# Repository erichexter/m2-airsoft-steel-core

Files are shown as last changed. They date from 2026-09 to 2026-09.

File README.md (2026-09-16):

# M2 Airsoft — Steel Core Conversion

> **Part names.** Every part has one name, used identically in Fusion, in `stl/`, and in
> these notes — `ST-` you weld, `HW-` you buy, `PR-` you print. See **[docs/PARTS.md](docs/PARTS.md)**
> for the full catalogue and the old-name mapping. Note that **L and R are the physical
> sides of the gun**, and the donor mesh names had them backwards.

A welded steel structural core for a 3D-printed Browning M2 airsoft replica.

The assembled replica

*Blue is steel you weld, brass is hardware you buy, grey is 3D printed.*

**▶ [Three-minute walkthrough video](https://github.com/erichexter/m2-airsoft-steel-core/releases/tag/v1.0)**
— cross-sections, what is steel, how it goes together.

Instead of printing the receiver as a structural part, this design puts all the load into a
single piece of **2" × 3" × 0.120" wall rectangular steel tube**. The printed parts become
non-structural cosmetic skins that bolt and glue over it, plus a printed cradle that carries the
airsoft engine and hop-up.

The result is stiffer, survives being carried by the barrel or dropped, and puts the hinge,
pintle and barrel mounts into welded steel rather than plastic.

**~11.2 lb of steel** (including the EMT barrel) and **~3.6 lb of PLA** — call it **~17 lb
finished** with the engine and hardware. The PLA figure assumes a 2mm shell and light infill;
printed solid the same parts would be 8.9 lb.
For scale: a real M2HB is 84 lb; commercial airsoft M2 replicas run 33–44 lb.

---

## What's here

```
docs/PARTS.md              Parts catalogue — every name, in one place. START HERE
docs/PRINTING.md           Orientation per part, settings, and why the long panels warp
docs/SLICER-AGENT-PROMPT.md  Self-contained brief to hand an agent on the slicer machine
docs/BUILD-NOTES.md        Full build notes: cut list, coordinates, weld plan, gotchas
docs/NATIVE-REBUILD.md     How the donor meshes were reauthored as native geometry

stl/PR-*.stl               The 18 printed parts, ready to slice
stl/print-aids/            PR-11/PR-12 with snap-off corner pads — print THESE two
stl/ST-*.stl               Steel parts — for checking the cut list, not for printing
stl/donor/                 Original donor meshes, kept for reference and attribution

cad/10_Steel_Core.stp      One STEP per component group
cad/20_Print_Receiver.stp    …
cad/M2_core_tube_RFQ.stp   Core tube alone — upload this for a laser-cut quote
cad/M2_steel_core.stp      Full steel assembly + engine cradle
cad/RFQ-core-tube.md       Stock spec, feature table, vendor notes

source/                    Fusion 360 archive (.f3d)
tools/stlcheck.js          Printability checker — run it on the STLs
tools/reauthor/            Mesh-to-native toolchain and the per-part build scripts
LICENSE                    CC BY-NC-SA 4.0
```

The STEP and STL files contain **only original work** — the steel design, the printed skins
derived as described under ATTRIBUTION, and the cradle.

### Getting the STLs

**Easiest: grab the print pack from the
[latest release](https://github.com/erichexter/m2-airsoft-steel-core/releases/latest).**
The print pack ZIP there has the 18 printed parts and both tube templates in one
download — no clone, no git-lfs, nothing to configure. Always take the **latest**
release; earlier packs are left up for reference but are superseded.

That matters because **the STLs, STEPs and renders are stored in Git LFS, and two of
the obvious ways to download them silently give you 131-byte text pointers instead of
models.** Release assets are served directly and sidestep it entirely. Verified
against this repo:

| how | what you get |
|---|---|
| **Code → Download ZIP** | ❌ pointers — all 40 STLs come to **5 KB total** |
| `raw.githubusercontent.com/…` | ❌ pointer |
| **Download button on the file's page** | ✅ the real STL |
| `github.com/erichexter/m2-airsoft-steel-core/raw/main/stl/<name>.stl` | ✅ the real STL |
| `git clone` **with git-lfs installed** | ✅ everything |

A pointer file is 131 bytes of text beginning `version https://git-lfs…`. If a
download is that size, that is what happened.

To get the whole set at once, install [git-lfs](https://git-lfs.com) *first*, then:

```
git lfs install
git clone https://github.com/erichexter/m2-airsoft-steel-core.git
```

Cloning **without** git-lfs installed also gives you pointers. If that has already
happened, `git lfs install && git lfs pull` fixes it in place. Either way, check
before slicing:

```
node tools/stlcheck.js stl/PR-*.stl
```

which fails loudly on a pointer file rather than letting a slicer choke on it.

### Checking the prints

```
node tools/stlcheck.js stl/PR-*.stl
```

Reports triangle count, watertightness (open and non-manifold edges), degenerate facets,
connected shells, bounding box against the bed, normal orientation, and overhang burden for each
axis-aligned orientation. All 18 printed parts are closed — **zero open edges** — with correct
normals and a single shell.

Two reported conditions, both understood and both fine:

- **`PR-16-Top-Cover.stl` "does not fit the bed".** The checker only tests axis-aligned
  orientations. The cover is 329.9 mm long and does fit laid diagonally — measured by rotating
  its actual first-layer point set, the best angle is **45°, giving 272.7 × 272.4 mm — 13.6 mm
  of margin per side**, which is room for a 10 mm brim. An earlier note here said 294 mm and
  5.7 mm; that was an estimate, not a measurement, and it was wrong.
- **`PR-31-Spade-Grips.stl` reports 3 non-manifold edges.** They are three 2 mm verticals at
  X ≈ −583, Y ≈ ±10, where the trigger's clearance slot cuts through the spine and the cut
  surface meets itself. The part has **no holes** and is one closed shell; slicers handle
  touching edges without complaint.

---

## What it looks like

| | |
|---|---|
| Steel core | **The steel.** One 2×3 tube plus eleven welded pieces. Everything else hangs off this. |
| Receiver skins | **The printed receiver skins.** Nine parts that clothe the tube and carry no load. |
| Trigger group | **Trigger.** Butterfly on a ⌀4 pin through both tube walls; the switch sits *above* the tail, so pressing down closes it. |
| Charging handle | **Charging handle.** The carrier sandwiches the tube wall through the existing slot; four ⌀8 nut pockets in the arm. |
| Barrel mount | **Barrel.** 1" EMT in a welded socket, two set screws, reachable through the jacket perforations. |
| Grips and backplate | **Grips.** Bolted, not welded — the backplate comes off to service the trigger. |
| Engine cradle | **Engine.** PolarStar F2 with the direct-attach combo, in a printed cradle. |

Every image above is rendered straight from the model by `tools/reauthor/render_docs.py`,
so they cannot drift from the geometry.

---

## Design summary

**Core tube** — 2" × 3" × 0.120" wall, 22-7/8" long, offset 8mm below the barrel axis so the
front mounting bore clears the floor. Cut for a top opening, a belt slot, a charging-handle shaft
slot through both walls, an air-line pass-through, and the front mounting bore.

**Weldments**
- Pintle tabs ×2, 1/2" plate, tapered with a ⌀12 bore
- Hinge tabs ×2, 1/8" plate, mounted **inside** the tube with a round head concentric with the
  pin so the cover's relief is a plain circular pocket and rotation is free by construction
- Hatch spine, 1/8" × 1" flat, inlaid into the cover so hinge load never passes through plastic
- Barrel plate, 1/4", welded across the open tube end
- Barrel socket, 1-1/2" OD × 1.188" ID DOM
- Backplate bosses ×2, 1/2" bar, welded down the inside of the rear walls, tapped 4 × M5

**The backplate is bolted, not welded** — 4 × M5 into those bosses. Welding it shut would seal the
trigger away permanently: the mechanism sits at X −580…−526, well behind the tube's top opening
(X −310…−2), so there would be no access to it at all.

Disassembly, verified by sweeping each part clear:

1. Drift the ⌀4 pivot pin out through the **⌀6 hole in `PR-11-Side-Rear-L`** at X −552, Z +1
2. Draw the trigger straight back — the lever slides out through the backplate slot
3. Undo 4 × M5 and the backplate lifts off, **bringing the switch carrier with it**

The pin cannot retain the backplate, in case it looks like it should: the pin is at X −552 and
the backplate at X −563.18…−560, so they never intersect.

**Charging handle** — slides, spring returns, **150 mm of travel**, and it runs in the
**existing 192 × 8 mm slot**. No extra metal is removed for it and **no guide rod is used** —
three printed parts sandwich the receiver wall and the slot itself is the track:

| Part | Where |
|---|---|
| `PR-43-CH-Shoe` | inside the tube, Y −22…−14, 16 mm tall behind an 8 mm slot so it can't pull out |
| `PR-42-CH-Carrier` | 7 mm neck through the slot, pad outside the panel at Y −38…−30 |
| `PR-41-CH-Handle` | full-length foot bolting to the pad, 1,696 mm² of flat contact |

The shoe and carrier clamp a 7.65 mm stack — skin plus steel wall — across an 8 mm neck, leaving
**0.35 mm of running clearance**. Two M4 bolts hold the sandwich; four **M6** into heat-set
inserts in the handle's own foot carry the pull. Assemble the handle to the carrier off the gun,
then fit the pair and add the shoe.

To install the shoe, turn it 90° about its long axis so its 8 mm edge is vertical, pass it through
the slot, and rotate it home.

**Trigger** — the butterfly and its lever are **one printed part**. It runs through a slot in the
backplate and pivots on a ⌀4.2 pin passing through **both tube side walls** at X −552, so the
pivot is anchored in steel rather than plastic. A tail forward of the pivot works a microswitch
carried on a small printed mount bolted to the backplate's inner face.

The F2 is electronic, so the trigger only has to close a switch — nothing mechanical reaches the
engine, and only the wires run forward. Lever ratio is 51 mm at the thumb against 18 mm at the
tail: **6° of travel gives 5.3 mm at the thumb and 1.9 mm at the tail**, where a typical
microswitch needs about 0.5 mm. Return and resistance come from a torsion spring on the pivot pin;
there's a ⌀3 peg hole in the tail if you'd rather hang a tension spring off it.

Verified clear of the tube, backplate and switch mount through 10°.

Swept in 25 mm steps against the tube, the side panels, the pintle tab, the backplate and the
cradle: 0.0000 cm³ throughout.

The return is **elastic shock cord, not a steel spring** — 150 mm of travel would need a
~350 mm compression spring and there is only 230 mm of clear tube behind the carrier. Anchor the
cord at the barrel plate and route it down the **left side at Y −20, Z −30**: that misses the
cradle (which reaches Y −18), the F2 (Y ±12.7), the hinge tab (Z −20 and up) and the pintle tabs
(Z −35 and down). It is the one path through that is clear end to end.

**The barrel is 1" EMT conduit.** OD 1.163", and the DOM socket's 1.188" ID takes it with 0.64mm
of clearance and the full 100mm of socket engagement. Cut it **39-1/4"** (996mm) measured from
where it bottoms in the socket. Note that 1" *pipe* of any schedule is too small — NPS is
nominal, and 1" sch40 has a 1.049" ID.

**The perforated barrel jacket is printed** and slides over the EMT — it's the M2's signature
feature and the one part of the barrel worth printing. 262mm long, ⌀101.6 at the rear flange,
bored ⌀38.90 over the steel socket and ⌀30.20 for the EMT, with a centring ring at the muzzle end
so it can't flop about on the conduit. Stood on end it fits a 300mm bed with 38mm to spare.
Forward of the jacket the EMT is bare.

It runs back to **X 24.80** so it meets `PR-17-Front-Sight-Boss` flush — its rear is pocketed to clear the 1/4"
barrel plate, which would otherwise show through. **Bond that joint with epoxy; it needs no
fasteners.** The butt gives **1,615 mm² of face-to-face contact**, several times what an epoxy lap
joint requires, and the jacket is already located by the ⌀38.90 bore over the steel socket across
87mm of engagement — so it cannot shift radially and only the axial pull needs carrying. Bolts
were considered and rejected: the joint face is buried under 260mm of jacket from the front and
38mm of PR-17-Front-Sight-Boss from the rear, so no fastener is reachable once assembled.

### The barrel comes off without disturbing the jacket

**2 × M5 set screws tapped into the socket** at X 55 and X 75, entering from underneath and
bearing on the EMT. The socket wall is 3.96mm, so an M5 gets full thread depth. They close a
0.32mm radial gap (socket ID r15.09 against EMT OD r14.77) — dimple the EMT at both positions so
the screws locate positively rather than relying on friction.

The screws sit under the jacket, so the jacket carries **2 × ⌀7 access channels** straight up from
its underside. A 2.5mm hex key reaches both screws with the barrel fully assembled — verified
clear through jacket, socket and EMT. Slacken both and the barrel slides straight out forward;
swept 150mm with no catch.

X 55 and 75 were chosen because X 95 lands on one of the jacket's cooling holes.

EMT is galvanised. Scuff and etch-prime it before painting or nothing will stick, and **do not
weld or braze it** — heating zinc gives off fumes that will make you ill. It doesn't need welding
here; it's a slip fit into the socket.

The socket runs X 13.65…113.65 and the jacket X 26.75…287, so the steel is completely hidden
inside the printed jacket. Nothing of it shows.

**Engine** — PolarStar F2, HPA. No battery bay needed; the air line exits through the tube floor.

**Panels screw on — 36 × M3.** Thread-forming button-head screws through the panel into ⌀2.65
pilot holes drilled in the tube wall. No tapping and no rivnut tool; the wall is 0.120" so a
thread-former cuts a full-depth thread on the way in. Heads sit proud, reading as the M2's rivet
line rather than being hidden.

| Panel | Screws | Where |
|---|---|---|
| `PR-12-Side-Rear-R`, `PR-11-Side-Rear-L` | 6 each | X −525.1 / −460.1 / −285.7, at Z −24 and +8 |
| `PR-14-Side-Front-R`, `PR-13-Side-Front-L` | 6 each | X −242.4 / −122.9 / −63.1, at Z −24 and +8 |
| `PR-15-Top-Deck` | 6 | X −526.7 / −413.5 / −356.9, at Y ±18 |
| `PR-18-Bottom-Rear` | 6 | X −516.3 / −442.4 / −294.6, at Y ±18 |

Every panel carries a **⌀8 boss on its inner face at each screw**, bridging the 0.4 mm clearance
gap to the tube so the screw clamps against solid material instead of flexing a 3 mm shell.

**`PR-19-Bottom-Front-L` / `-R` are bonded, not screwed.** They are two thin rails sitting over the tube's bottom corner
radii — there is no flat there to pull against. `PR-17-Front-Sight-Boss` is bonded too, to the barrel jacket.
The pilot holes are on the wrap template in `templates/`.

See [docs/BUILD-NOTES.md](docs/BUILD-NOTES.md) for the full cut list, every coordinate, the weld
plan, and the fabrication order.

---

## Stock list

All imperial, 12" minimum lengths, cut to length only — no rip cuts.

| # | Stock | Grade | Buy | For |
|---|---|---|---|---|
| 1 | 2" × 3" × 0.120" wall rect tube | A500 Gr B | — | Core tube — **supplied by the laser vendor, don't buy separately** |
| 2 | 1-1/2" OD × 1.188" ID | **DOM** | 12" | Barrel socket |
| 3 | 1/2" × 2" flat bar | A36 HR | 12" | Pintle tabs ×2 + backplate bosses ×2 |
| 4 | 1/4" × 3" flat bar | A36 HR | 12" | Barrel plate |
| 5 | 1/8" × 1" flat bar | A36 HR | 24" | Hatch spine + hinge tabs |
| 6 | 1/8" × 3" flat bar | A36 HR | 12" | Backplate |
| 7 | 1/4" round bar | 1018 CRS | 12" | Hinge pin |
| 8 | 1/2" round bar | 1018 CRS | 12" | Pintle pin |
| 9 | 9/16" round bar | 1018 CRS | 12" | Front mount pin |
| 10 | 1" EMT conduit | — | 10 ft | **Barrel** — cut 39-1/4", the rest is spare |

**A36 hot-rolled** is the cheap general-purpose structural grade — fine for tabs and plates that
get welded. **1018 cold-rolled** is used for the three pins only: hot-rolled round bar carries mill
scale and a loose diameter tolerance, so it will not slip-fit a bore.

Pin bores are cut **0.30 mm over** nominal bar (⌀6.65 / ⌀13.0 / ⌀14.6) so imperial stock drops in.
Don't "correct" them to round metric numbers — 1/4", 1/2" and 9/16" bar is 6.35, 12.70 and
14.29 mm, and a 12 mm bore will not accept a 1/2" pin.

**Item 2 is the one place not to substitute.** ERW tubing is cheaper but has an internal weld
bead, and the socket has only 0.64 mm of clearance on the EMT. DOM has a clean ID.

---

## Status

Working design, not yet fabricated. Every part has been checked against every other part with no
interference, and every mechanism swept through its full range.

**The donor-derived parts are faceted STL conversions.** Everything designed here is native
geometry, so the tube STEP a fabricator receives is clean (135 faces, 73 real cylinders). The
barrel jacket has been reauthored natively — **17,422 faces down to 60** — and the rest are
tracked in [docs/NATIVE-REBUILD.md](docs/NATIVE-REBUILD.md). Fusion cannot convert them
automatically; see the build notes.

Open items, all of which need hardware in hand rather than more CAD:

- Shock cord for the charging handle return is specified by routing, not by rate — pick a cord
  and check the return force by hand before committing to the anchor point
- The barrel jacket's fit on the EMT is set by the centring ring alone; if it rattles, shim it or
  add a second ring partway along
- Print tolerance on the ⌀38.90 jacket bore over the ⌀38.10 socket: FDM holes come out undersized,
  so print a short test ring before committing 260 mm of filament

Decided, not open:

- **Pin positions stand as designed.** Hinge, pintle and front-mount pins are inferred from the
  donor model rather than measured off real hardware, and that is accepted — the mounts are
  tolerant enough that a few millimetres either way does not matter.
- `PR-19-Bottom-Front` used to be one body containing two disconnected rails; it is now
  two parts, `-L` and `-R`, which is what a slicer made of it anyway
- `PR-16-Top-Cover` is 329.9 mm and only fits the bed laid diagonally (294 mm footprint, 5.7 mm margin)
- The steel backplate cannot merge with any printed part — different material and process. The
  grip and buffer tube are already merged into `PR-31-Spade-Grips`.

---

## ATTRIBUTION

The cosmetic skin geometry is **derived from**:

> **M2 Browning 0.50 cal Machine Gun (1:1 Scale)** by **HappyBattleSheep**
> https://www.thingiverse.com/thing:7248430
> Licensed **CC BY** (Creative Commons — Attribution)

Specifically, the skins are cut from that model's `corpus` part. The steel core, the engine
cradle, the weldments, the tooling and the documentation are original work.

The source is CC BY, which permits derivatives and redistribution provided the original author is
credited. That credit is the line above — **keep it if you fork this.** CC BY is not share-alike,
so this derivative may carry the more restrictive CC BY-NC-SA in [LICENSE](LICENSE); that applies
to the original contributions here and cannot revoke anyone's rights to HappyBattleSheep's work,
which remains available under CC BY from the link above.

The upstream model pack is not vendored into this repo — download it from Thingiverse.

The PolarStar F2 engine and FCU CAD models are the property of PolarStar Airsoft and are
referenced for fitment only. They are not included in this repository.

---

## Note

This is an **airsoft replica** — a non-firing recreational replica that launches 6mm plastic BBs
at sub-lethal energies. It has no capability to chamber or fire live ammunition, and nothing here
describes or enables that.

Local law on replica firearms varies. Orange muzzle markings are required in some jurisdictions
and transport rules differ by region — check yours.

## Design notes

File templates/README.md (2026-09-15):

# Wrap-around cutting template — 2×3 core tube

For marking out the tube by hand. Generated from the model, not transcribed:

```
node tools/makewrap.js wrap.json templates
```

| | |
|---|---|
| `wrap.json` | the source data — unrolled outlines, fold lines, extents |
| `M2_tube_wrap.pdf` | **plotter-ready**, one page, media declared as exactly 619.52 × 273.53 mm |
| `M2_tube_wrap.svg` | the same drawing as vector source, for editing |
| `M2_tube_wrap_plot.html` | what the PDF is rendered from — print this if you'd rather not use the PDF |
| `M2_tube_wrap_letter.pdf` | the same drawing across **6 letter pages**, 12 mm overlap |
| `M2_tube_wrap_tiled.html` | what the letter PDF is rendered from |

The PDF is regenerated from `M2_tube_wrap_plot.html` with:

```
chrome --headless --no-pdf-header-footer \
       --print-to-pdf=templates/M2_tube_wrap.pdf templates/M2_tube_wrap_plot.html
```

## Printing it

### At home — 6 letter sheets

Open `M2_tube_wrap_tiled.html` in Chrome or Edge and Ctrl-P:

| setting | value |
|---|---|
| Paper | Letter |
| Layout | Landscape |
| Margins | **Default** — the page sets its own 8 mm; "None" also works |
| Scale | **Custom → 100**, never "Fit to printable area" |
| Headers and footers | **off** — they push the drawing and force a rescale |

Six sheets come out labelled `r1c1 … r2c3`, row-major: top row left→right is the
breech half, bottom row is the muzzle half. **Measure the 100 mm bar on every sheet
before you cut anything** — it is printed on all six, because duplex and n-up
settings can scale sheets unevenly. Then trim each sheet on the grey corner crop
marks, overlap 12 mm, and tape.

### Plotter — one sheet

Plot `M2_tube_wrap.pdf`. Its media size is declared as exactly 619.52 × 273.53 mm,
so there is nothing for the driver to decide. Two settings still matter:

- **Sizing / scaling: Actual size — 100%.** Not "Fit to page", not "Shrink oversized
  pages", not "Scale to roll width". A plotter driver handed a page that is not a
  standard size will scale it to one unless told otherwise, and 619.52 mm is not a
  standard size.
- **Rotate / autorotate: off.** Autorotate is harmless on its own, but it is usually
  bundled with fit-to-media in the same driver preset.

Feed it at least **630 mm** of roll — 24" (610 mm) is **9.5 mm too narrow** to take
the sheet across the roll, so on a 24" machine plot it *along* the roll instead.
36" (914 mm) takes it either way. A1 (594 × 841) works in landscape.

Measure the 100 mm bar on the plot before cutting. The PDF itself is 1:1 to within
0.0004 mm over that bar — anything you measure past about 0.5 mm came from the
driver, not the file.

If your workflow wants vector rather than PDF, `M2_tube_wrap.svg` is the same
drawing — but note that an application handed a bare SVG picks its own paper size
and then scales to fit it, which is exactly the failure the PDF exists to prevent.

## Using it

The drawing is the tube's perimeter unrolled flat. **The seam is on the bottom
centreline**, so the wrap runs: bottom(right half) → right side → top → left side →
bottom(left half). Breech is at the left of the sheet, muzzle at the right.

1. **Check the scale first.** There is a 100 mm calibration bar on the single sheet
   and on every one of the six tiled sheets. Measure them. If one isn't 100 mm your
   printer scaled the page and everything downstream is wrong — reprint with scaling
   off ("Actual size" / 100%, not "Fit to page").
2. Wrap it around the tube with the paper's edge flush to the **breech end** and the
   seam running down the **bottom** face centreline. It should meet itself exactly —
   the perimeter is 243.53 mm.
3. Tape, then centre-punch or scribe through the outlines.

## Reading the drawing

- **Solid black** — cut these.
- **Red dashed** — corner tangents, i.e. where the tube's R0.240" radii begin. These
  are fold lines for the paper, **not cuts**. They also tell you when a cut crosses a
  corner rather than staying on a flat.
- **Grey dashed rectangle** — the wrap boundary.
- **Grey vertical lines** — every 50 mm, labelled with the model's X coordinate.
  X is negative toward the breech; X 0 is near the muzzle end, so the numbers count
  up as you move right.

## Watch for

**The air line hole sits on the seam.** It's ⌀12.7 centred on the bottom centreline
at X −410, so it appears as two half-circles, one at each edge of the sheet. They
join when wrapped.

**The top opening runs corner to corner.** The cut at Z +24 lands 0.004 mm below the
corner tangent, so over X −310…−2 the entire top face and both upper radii are
removed. On the flat it is the full band between u 92.88 and 150.65.

**The belt slot and the top opening are one aperture.** They meet at X −141 and there
is no web between them.

**Locating tabs are material to leave, not remove.** Both ends carry 25 mm tabs on the
top and bottom faces — front at X +20…+26.35, rear at X −563.18…−560. Cut around them.

## Known model artifact

The tube body carries some 0.01 mm proud steps on the left wall, left over from
filling in an earlier charging-handle aperture. They are filtered out of this template
(by face area and coplanar-normal tests) and are far below any hand-marking tolerance,
but they are why the body has 101 faces where a clean build has 81. Worth rebuilding
the tube from the canonical script before sending the STEP anywhere for quoting.

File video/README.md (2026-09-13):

# Video pipeline

Builds a narrated walkthrough from the Fusion model. The render frames and the
finished mp4 are **not** committed — they are ~1 GB and ~70 MB respectively.

```
narration.md   the script; each "## NN_name" block becomes one VO clip
tts.js         renders each block to vo/NN_name.mp3 via ElevenLabs
build.sh       frames + vo -> M2_steel_core.mp4
```

## Running it

1. **Render frames from Fusion.** Seven sequences at 1920×1080, written to
   `<work>/hero`, `steel`, `section`, `ch`, `trig`, `barrel`, `explode`.
   Driven by `Viewport.saveAsImageFile` in a loop — see the build notes for the
   camera paths. `hero` and `steel` must share the same camera path, because the
   reveal crossfades one into the other.
2. `ELEVENLABS_API_KEY=... node tts.js [voiceId]` — default voice is Roger
   (`CwhRBWXzGAHq8TQ4Fs17`), conversational American, which suits a maker video.
3. `bash build.sh`

## How the timing works

There is no separate edit. **Each video segment is built to the exact duration of
its narration clip**, so the cut always lands on the sentence. Change a line of
narration, re-run `tts.js`, re-run `build.sh`, and the picture re-times itself.

Drift is about 0.2 s across three minutes — each segment rounds up to a 24 fps
frame boundary. Not worth correcting.

## Gotchas

- Sequences that travel linearly (`section`, `barrel`, `explode`) are built
  **ping-ponged** (forward then reversed) so they loop seamlessly when stretched
  to fill a narration block. Turntables loop naturally and are not ping-ponged.
- `drawtext` on Windows needs the font path escaped as `C\:/Windows/Fonts/...`.
  Avoid apostrophes **and colons** in title text — both terminate the filter
  string. A subtitle reading "1:1 scale" fails to parse; "full scale" works.
- Mesh-derived bodies (jacket, grip, handle) carry **face-level** appearances that
  override `body.appearance`, so they cannot be recoloured in bulk. Iterating
  20k faces to fix that hangs Fusion. This is why the metal/plastic story is told
  by hiding the printed parts rather than by colour-coding them.

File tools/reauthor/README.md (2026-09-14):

# Reauthoring tools

Turning a donor STL skin into native Fusion geometry. The method that works is
**measure the mesh, straighten the measurements, author from clean primitives** —
never trust a mesh-to-BRep convert, and never approximate a plate with a loft.

## The pipeline

```
bbox.js        bounding box + dominant facet normal, to find the plate axis
scanx.js       cross-sectional area vs station -> where the prismatic runs and
               the breakpoints are.  THIS IS THE FIRST THING TO RUN.
profile.js     exact cross-section at one station, chained into loops, holes
               classified by containment, corners preserved (RDP)
snap.js        straighten: heavy RDP, then cluster coordinates onto shared values.
               The M2 is a 1918 sheet-and-plate design; mesh wobble is scan noise.
               Also splits ROUND loops out of the profile into `circles` (holes)
               and `discs` (rivet heads) so the build can cut/add them as real
               cylinders - a circle that goes through RDP comes back a triangle.
ascii.js       print a profile as an ASCII occupancy map so you can see it
discprofile.js measure a raised/recessed feature's diameter along its axis and fit
               a sphere, so a DOME can be told from a cylinder or a cone
revprof.js     first-hit radius on an (axis, theta) grid - proves whether a part is
               a body of revolution, and gives its radius profile if it is
sections.js    many sections at once, for the rare part that really is lofted
silhouette.js  rasterised projection outline (useful, but see the warning below)
_lib.py        Fusion side: sketch a region on any plane, extrude it, loft between
               regions, plus mm-based box/cylinder primitives
```

Typical run:

```bash
node scanx.js Hatch.stl x -334 -4 5            # find the runs
node profile.js Hatch.stl x -180 0.15 --json h_main.json
node snap.js h_main.json 0.6 0.05 0.30         # -> h_main_s.json
node ascii.js h_main_s.json                    # eyeball it
```

then feed the snapped regions to `extrude_region` / `loft_regions` in Fusion.
`build_hatch.py` and `build_top1.py` are worked examples.

## Warnings paid for the hard way

- **Vertex-based slab filtering fails on prismatic runs.** A 200 mm straight run
  carries vertices only at its ends — one triangle spans the whole length. Filtering
  triangles "whose vertices lie in X between a and b" returns nothing in the middle
  of the part. Always slice with a plane (`profile.js`), never bin vertices.
- **Booleans against faceted bodies lie.** The donor hatch reported *clear* of the
  steel hinge tabs while being solid straight through them. Cross-check any
  mesh-body clash result by intersecting with small probe boxes and reading volumes.
- **`tbm.booleanOperation` returns a bool, not a body.** Assigning its result to the
  body variable stores `True` and the next call dies. Four times now.
- **Don't loft a shape whose character changes.** Lofting the trigger's butterfly
  paddle produced melted geometry three different ways (arc-length resampling,
  angular resampling, and two-view silhouette intersection). Loft only where the
  section stays the same *kind* of shape along the run.
- **Snapping must not eat real dimensions.** An early pass rounded 12.70 — half an
  inch, the tube notch — up to 13. Keep the round-number tolerance under 0.06 mm.
- **Audit bounding boxes against the donor.** Four parts were built short because a
  run was stopped at a round number instead of where the geometry ends. Volume
  comparison hides this — 0.35 mm of missing boss costs almost no volume — but a
  bbox diff catches it instantly, and it needs no CAD package.
- **Check whether a round feature is a DOME before building it.** Every raised disc
  on this gun is a spherical rivet head, and the recessed ones are spherical dimples.
  Fit r² = R² − (s − c)²; a real sphere fits to under 0.3 mm. Remember a dome is a
  whole sphere, so its far half sits inside the part and can break out the back.
- **Never approximate a revolve with a stack of cone segments.** It is geometrically
  fine and renders as visible rings — it looks knurled. One `revolveFeature` through
  a fitted spline is 3 faces and actually smooth.
- **Put hole topology in any band-merge signature.** Merging bands keeps the first
  one's profile, so a slot that appears in only some of them is silently filled in.
- **`feature.bodies.item(0)` is wrong in a direct-design document.** It hands back
  the component's FIRST body, not the one the feature just made. That looks right
  only while each part sits alone in an empty component — the moment several parts
  share one, builds start swallowing their neighbours. Take the last body instead.
- **Fusion returns a fresh wrapper object on every access**, so `occurrence is
  target` is always False. Comparing identity instead of name silently hid every
  body and produced 29 empty STL exports that all reported success.
- **Anything that looks a body up by name breaks on a rename**, silently. Count
  what you matched and print the count.
- **Relief cuts want a little clearance, but not much.** Zero leaves coincident
  faces that tessellate non-manifold; 0.25 mm severed a thin mounting tongue into
  its own shell. 0.05 mm, plus `drop_debris()` to sweep up the wafers, worked.

## The build scripts

Worked examples, one per part, all run the same way: `exec` `_lib.py`, then the
part's profile data, then the build. Each writes straight into its catalogue
component under its catalogue name (see `docs/PARTS.md`), so rebuilding one part
leaves its neighbours alone.

`naming.py` + `reorganize.py` are the one-shot that applied the naming convention
to the whole model.

`render_docs.py` regenerates every image in `docs/img/` — nine assembly views and
one shot of each of the 32 parts. It colour-codes by class for the renders (steel
blue, hardware brass, printed grey) and puts the model's appearance back afterwards.
**Re-run it after any rebuild** so the pictures cannot drift from the geometry. It
takes a couple of minutes; run the assembly views and the part views as separate
calls or the Fusion MCP call times out (the renders still complete).

```
build_top1.py       simplest - six prismatic runs and six blind holes
build_hatch.py      prismatic runs, straight ramps, swept hinge clearance
build_side2.py      layered plate, one function building both hands via a sign flip
build_side1.py      five stepped tiers, rivet heads, d19 boss
build_side1r.py     same, plus arithmetic rivet rows and a trimmed overhang
build_frontboss.py  six runs including twelve rectangular standoff ribs
```

Two habits worth keeping:

- **Generate regular patterns arithmetically, don't read them back.** Reading the
  rear rivet rows off the mesh missed a head and gave different diameters row to
  row. Two lines of `start + pitch * i` is exact and self-documenting.
- **Build mirrored parts from one function with a sign parameter.** `Side_L2` and
  `Side_R2` differ in exactly two features; a shared builder makes that explicit
  instead of letting the pair drift.

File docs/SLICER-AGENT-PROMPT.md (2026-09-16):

# Prompt for an agent on the slicer machine

Copy everything below the line into an agent running on the machine that has Creality
Print (or OrcaSlicer) installed. It is self-contained — it assumes no knowledge of this
repo or of the conversation that produced it.

---

I need you to slice some 3D-printed parts for a Creality **K1 Max** and prepare them for
printing. **Do not start a physical print** — prepare the plates, save the project/G-code,
and tell me what you did so I can review and start it myself.

## Printer and process

- Creality K1 Max, build volume 300 × 300 × 300 mm — **confirm which plate is fitted; do
  not trust the slicer profile's plate type, it says textured on a machine running smooth PEI**
- **0.6 mm nozzle, 0.3 mm layer height**
- PLA
- These are non-structural cosmetic panels — **do not print solid.** 3–4 walls and
  light infill (10–15% gyroid) is plenty. Total across all parts is ~3.5 litres of
  material, so infill choice matters a lot.

## Getting the files

The models are in a public GitHub repo. **They are stored in Git LFS**, which means two of
the obvious download routes silently return 131-byte text pointers instead of models:

- ❌ "Code → Download ZIP" — gives pointers
- ❌ `raw.githubusercontent.com/...` — gives a pointer
- ✅ `https://github.com/erichexter/m2-airsoft-steel-core/raw/main/<path>` — real file
- ✅ the release assets below — real files

**A pointer file is ~131 bytes of text starting `version https://git-lfs`. If a download is
that size, that is what happened — do not feed it to the slicer.**

Easiest: get the whole pack from the latest release, which is served directly and has no
LFS problem:

```
https://github.com/erichexter/m2-airsoft-steel-core/releases/latest
```

Download `M2-steel-core-print-pack-v1.4.zip` (or whatever the newest is) and unzip. The 18
parts are in `print/`.

**Then replace two of them.** `PR-11` and `PR-12` in that pack are the plain versions; use
these instead, which have sacrificial corner pads added:

```
https://github.com/erichexter/m2-airsoft-steel-core/raw/main/stl/print-aids/PR-11-Side-Rear-L-ears.stl
https://github.com/erichexter/m2-airsoft-steel-core/raw/main/stl/print-aids/PR-12-Side-Rear-R-ears.stl
```

Verify each downloaded STL is hundreds of KB, not 131 bytes, before slicing.

## Orientation — the most important instruction here

Every panel must be laid **inner (tube-mating) face DOWN on the bed, visible face UP.**
The parts were specifically reworked so that face is flat; printing them on any other face
throws that away and needs support everywhere. The correct face is the one listed:

| file | put this face on the bed | footprint |
|---|---|---|
| `PR-11-Side-Rear-L-ears` | **Y min** | 298 × 155 mm |
| `PR-12-Side-Rear-R-ears` | **Y max** | 298 × 155 mm |
| `PR-13-Side-Front-L` | **Y min** | 271 × 99 mm |
| `PR-14-Side-Front-R` | **Y max** | 271 × 99 mm |
| `PR-15-Top-Deck` | **Z min** | 226 × 51 mm |
| `PR-18-Bottom-Rear` | **Z max** | 296 × 51 mm |
| `PR-17-Front-Sight-Boss` | **X max** | — |

"Y min face on the bed" means rotate the part so the face at its lowest Y coordinate is
touching the plate. After orienting, confirm the part's flat face really is coplanar with
the bed — most slicers have a "place on face" tool; use it and pick that face.

For the parts not listed, pick the orientation with the largest flat face and the least
overhang.

## Two things that will go wrong if you ignore them

**`PR-16-Top-Cover` is 329.9 mm long and will NOT fit the 300 mm bed axis-aligned.**
Rotate it **45° about Z** — that gives **272.7 × 272.4 mm, 13.6 mm of margin per side**,
which is room for a 10 mm brim. The slicer will not work this out for you. If it still
will not fit, stop and tell me rather than scaling it.

**`PR-11` and `PR-12` with their pads are 297.6 mm across a 300 mm bed — 1.2 mm clear at
each end.** Centre them deliberately and confirm nothing is off the plate or inside any
exclusion zone. Print each of these **alone on the plate.**

## Settings

These address a real bed-adhesion failure on this exact machine — the long panels were
peeling their end corners off the plate. PLA contracts ~0.4% cooling, so a 296 mm part
shrinks ~1.2 mm along its length and levers its corners up.

Apply in this order of importance:

1. **Auxiliary / side fan OFF for the first ~10 layers.** The K1 Max stock PLA profile runs
   it hard and it blows straight across a 296 mm first layer. Biggest single lever.
2. **Part cooling fan 0% for layers 1–3**, then ramp to normal.
3. **First layer 30–50 mm/s** with reduced first-layer acceleration. Stock profiles are far
   faster and that is real shear on a marginally attached part.
4. **Bed 60 °C.** Tell me to let it soak 5+ minutes before starting.
5. **Brim on `PR-13` / `PR-14`** — they have 14 mm of spare bed. **No brim on `PR-11` /
   `PR-12`** — there is no room, which is exactly why those two have built-in corner pads
   instead.
6. Slight negative Z-offset if the profile allows — at 0.6/0.3 an under-squished first
   layer still looks acceptable.

Keep the enclosure **closed**. Chamber heat helps against warping here, even though stock
PLA profiles often suggest opening it.

## What to give me back

- One project/plate per part (or a sensible grouping), saved where I can find it
- Estimated time and filament per part
- Confirmation of which face ended up on the bed for each one
- Anything that did not fit, sliced oddly, or needed a judgement call

Do not send anything to the printer or to a cloud account. Stop and report.

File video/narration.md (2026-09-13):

# M2 Steel Core — narration script

Target ~2:40. Each block is one TTS render; filenames match `vo/NN_name.mp3`.

---

## 01_hook  (over: hero turntable)
This is an airsoft M2 replica. One to one scale, shoots six millimetre plastic BBs, and
almost all of it is 3D printed. But the part doing the work isn't printed at all. It's
a single piece of steel tube — and that one change turns a display piece into something
you can actually pick up by the barrel.

## 02_problem  (over: hero turntable continuing, then printed-only)
A printed receiver this size has a problem. It flexes. The model this is based on
solves it by running a four-foot wooden dowel down the middle and gluing everything to
it. That works, but the plastic is still carrying the load — every mount, every hinge,
every time you set it down.

## 03_idea  (over: crossfade full → steel only)
So here's the swap. One length of two-by-three rectangular steel tube, an eighth of an
inch wall, twenty-three inches long. Everything structural bolts or welds to that. The
printed parts stop being the gun and become skins over it.

## 04_steel  (over: steel-only turntable)
This is everything that's metal. The core tube. A quarter-inch plate welded across the
front. A DOM socket for the barrel. Half-inch tabs for the pintle. Eighth-inch tabs
inside the tube for the cover hinge, so hinge load never touches plastic. Eleven pounds
of steel, all of it standard imperial stock you can buy in twelve-inch lengths.

## 05_section  (over: cross-section sweep)
In section you can see how it works. The steel box runs the full length. It's designed
around a PolarStar F2 engine running the direct attach combo, so the hop-up and the
engine are one unit — that's what the printed cradle holds, and the whole thing drops
in through the top opening. The printed panels sit four tenths of a millimetre off the
steel and screw to it: thirty-six M3 thread-forming screws straight into the tube wall.
No tapping, no rivnut tool.

## 06_charging  (over: charging handle detail + travel)
The charging handle works. Three printed parts sandwich the receiver wall and ride in
the slot that's already there — no extra metal removed for it. A hundred and fifty
millimetres of travel, spring returned.

## 07_trigger  (over: trigger mechanism detail)
The trigger works too. One lever pivots on a pin through both tube walls, runs forward
through a slot in the backplate, and lifts a microswitch wired to the engine. Five
degrees of travel fires it. And the backplate bolts on rather than welding shut, so you
can still get at all of it.

## 08_barrel  (over: barrel jacket + EMT)
The barrel is one-inch EMT conduit — the electrical stuff, about twelve dollars for ten
feet. It slips into the socket with six tenths of a millimetre of clearance and a
hundred millimetres of engagement. Two set screws tapped into the socket hold it, and
the jacket has access holes underneath so a hex key reaches them. The barrel comes off
without taking anything else apart.

## 09_jacket  (over: jacket rotating)
The perforated jacket is the one part of the barrel worth printing. It's the M2's
signature, and it slides straight over the conduit.

## 10_outro  (over: hero turntable, then title card)
Every file is on GitHub — the STEP for the tube, the STLs, a one-to-one wrap template
you can print and tape around the steel to mark every cut and hole, and the full build
notes. Links below.

The skin geometry is derived from HappyBattleSheep's M2 on Thingiverse, used under
Creative Commons Attribution. The steel design and everything mechanical is released
Creative Commons non-commercial share-alike.

It's an airsoft replica. Check your local law on replica markings before you build one.

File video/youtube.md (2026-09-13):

# YouTube upload — paste-and-go

Upload file: `M2_steel_core.mp4` (1080p). Chapters are computed from the actual
segment durations in `build.sh`, so they stay correct unless the narration changes.

---

## Title

```
3D-Printed M2 Browning Airsoft Replica — With a Welded Steel Core
```

"Airsoft" is in the title deliberately, not just the description. YouTube's firearms
policy bars instructions for manufacturing firearms or firearm components; this is a
replica that fires 6 mm plastic BBs, but automated flagging does not read nuance, and
the title is the first thing it sees.

---

## Description

```
This is an airsoft M2 replica — full scale, shoots 6 mm plastic BBs, and mostly 3D
printed. But the part carrying the load is a single piece of steel tube.

A printed receiver this size flexes. The model this is based on solves it with a
four-foot wooden dowel down the middle. This replaces that with one length of 2" x 3"
x 0.120" wall rectangular steel tube, 23" long. Everything structural welds or bolts
to it, and the printed parts stop being the gun and become skins over it.

Built around a PolarStar F2 engine running the direct-attach combo, so the hop-up and
the engine are a single unit — that is what the printed cradle is shaped to hold.

~11.2 lb of steel, ~3.6 lb of PLA, ~17 lb finished. All the steel is standard imperial
stock you can buy in 12" lengths.

What works: a sliding charging handle with 150 mm of travel, a trigger that runs on a
pin through both tube walls and closes a microswitch, a hinged top cover on steel
hinge tabs, and a removable 1" EMT conduit barrel held by two set screws.

ALL FILES — CAD, STLs, build notes, and a 1:1 wrap template you print and tape around
the tube to mark every cut and hole:
https://github.com/erichexter/m2-airsoft-steel-core

CHAPTERS
0:00 What it is
0:18 Why a printed receiver flexes
0:37 The steel core
0:51 Everything that is metal
1:13 In section
1:41 Charging handle
1:54 Trigger
2:12 Barrel — 1" EMT conduit
2:36 The perforated jacket
2:43 Files and licence

CREDIT
Skin geometry is derived from "M2 Browning 0.50 cal Machine Gun (1:1 Scale)" by
HappyBattleSheep, https://www.thingiverse.com/thing:7248430, used under Creative
Commons Attribution. If you fork this, keep that credit.

The steel design, the mechanisms, the tooling and the documentation are released under
CC BY-NC-SA 4.0.

NOTE
This is an airsoft replica. It launches 6 mm plastic BBs at sub-lethal energies and has
no capability to chamber or fire live ammunition. Local law on replica markings and
transport varies — check yours before building or carrying one.
```

---

## Tags

```
airsoft, airsoft replica, m2 browning, ma deuce, 3d printing, 3d printed airsoft,
polarstar f2, direct attach combo, hpa airsoft, diy airsoft, fusion 360, steel fabrication, welding,
emt conduit, maker project, prop building, cosplay prop
```

---

## Settings

| | |
|---|---|
| Category | Science & Technology |
| Audience | **Not made for kids** |
| Licence | Standard YouTube licence (the CC BY-NC-SA on the files is separate) |
| Comments | on |

Do not crop or trim the outro — the attribution card near the end satisfies the CC BY
requirement on the derived skin geometry.

## If it gets flagged

Very likely to survive appeal: an airsoft replica is not a firearm, and the video shows
no live-fire capability. Point at the title, the outro card, and the fact that the
"barrel" is electrical conduit with no bore continuous to any chamber.

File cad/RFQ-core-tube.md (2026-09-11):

# RFQ — Laser-cut core tube

**File:** `M2_core_tube_RFQ.stp`
**Quantity:** 1

## Vendor — OSH Cut

**Order as: `3" x 2" x 0.12" wall - Rectangular A500 Cold-Formed Carbon Steel`**
(catalogue: app.oshcut.com/catalog/tube — in stock)

**Orient it 2" wide (Y) × 3" tall (Z).** The catalogue calls it 3 × 2; this design uses the 2"
dimension as the width. They accept STEP directly.

### Confirmed stock spec

| | |
|---|---|
| Outer | 3.000" × 2.000" |
| **Inner** | **2.760" × 1.760" = 70.10 × 44.70 mm** |
| Wall | 0.120" |
| Outside corner radius | 0.118" to 0.360" |
| Weld seam | Yes |
| Max length | 235" |
| Yield / Ultimate | 39 / 45 ksi |

The inner dimensions match this design exactly — every clearance was checked against
70.10 × 44.70 mm.

## Part

| | |
|---|---|
| Cut length | **23.210"** (589.52 mm) |
| Finished mass | 5.97 lb |
| Modelled corner radii | R0.240" outside, R0.120" inside |

Straight tube, both ends square. **The STEP carries A500 corner radii** — without them OSH Cut's
profile matcher identifies the section as aluminium extrusion, since nothing in their steel
catalogue has square corners.

## Features

| Feature | Face | Location | Size |
|---|---|---|---|
| Top opening | top | X −310 … −2 | **straight cut at Z +24, full width** |
| Belt slot | both sides | X −141 … −2 | open to the cut top edge, R4 bottom |
| CH shaft slot | both sides | X −540 … −348, Z −12…−4 | 192 × 8mm, R4 ends |
| Air line | bottom | X −410, centreline | ⌀12.7 (1/2") |
| Front mount bore | both sides | X +1, Z −33 | ⌀14.6 |
| Pintle notches | bottom corners | X −384 … −338 | for the 1/2" pintle tabs |
| Front locating tabs | top + bottom | X +20 … +26.35 | 25mm wide |
| Rear locating tabs | top + bottom | X −563.18 … −560 | 25mm wide |

The top cut is **one plane at Z +24** — the height where the corner radii begin, so it lands flat
on both side walls with no leftover arc, no flanges and no notches. Everything above goes.

Locating tabs at both ends are **exactly their plate's thickness** (1/4" front, 1/8" rear) so the
tab and plate faces finish flush — nothing protrudes. They pass through matching through-slots,
so the plates and the tube are both laser-only with no milled pockets anywhere.

Smallest feature is the 8mm CH slot — 67× the 0.120" wall.

The CH slot is symmetric — same 192 × 8mm on both sides. The left one doubles as the working track
for the charging handle; the carrier's neck is 7mm so it runs inside the 8mm slot with 0.5mm each
side. No separate track is cut.

## Notes for the vendor

- **The STEP declares centimetres** (`SI_UNIT(.CENTI.,.METRE.)`). That's Fusion's internal unit and
  it exports that way regardless of display settings. Valid STEP; any conforming reader scales it
  correctly. Flagged only so a 10× preview doesn't cause alarm. All dimensions here are mm and in.
- The top opening and belt slot **meet** at X −2 and form one continuous aperture. Modelled as a
  single cut — please don't leave a web between them.
- Over X −310 … −2 the tube is a U-channel by design. It is braced by weldments after cutting.
- ±0.005" is more than adequate. Feature positions matter more than overall length; the tube can
  run ±0.030" long without consequence.

## Two risks from the real profile

### Corner radius is a range
Spec is 0.118"–0.360". The model uses R0.240" outside (2× wall, conventional for 0.120"). If the
delivered tube lands at the large end, the flat bottom narrows and the **pintle tab notches** shift
relative to the corner. Measure the corner radius on arrival before welding those tabs.

### Internal weld seam
Position isn't specified and is usually on one flat face. It could foul the hinge tabs lapping the
inner wall or stop the cradle seating flat. **Locate the seam on arrival and orient the tube so it
falls on an unused face** — the right side above the CH slot is the least congested.

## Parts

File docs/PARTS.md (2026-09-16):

# Parts catalogue

Every part in the model has one name, and that name is the same in Fusion, in
`stl/`, and in the build notes.

```
<class>-<NN>-<Descriptive-Name>[-L|-R]
```

| class | meaning |
|---|---|
| `ST` | **steel** — you cut it and weld it |
| `HW` | **hardware** — you buy it (conduit, pins, switch, fasteners) |
| `PR` | **printed** — you print it |
| `RF` | **reference** — never built; donor meshes and bought-in models |

The number groups by subassembly: `0x` structure, `1x` receiver skins, `2x` barrel,
`3x` grips, `4x` charging handle, `5x` trigger, `6x` engine.

## Which side is L and which is R

**Standing behind the gun, firing forward.** The muzzle is +X, up is +Z.

The charging handle on a real M2 is on the **right**, and in this model it sits at
**negative Y** — so negative Y is the right-hand side. Everything below follows the
physical side.

> **The donor mesh names have this backwards.** Its `Side_L1` / `Side_L2` /
> `CH_Handle` are all at negative Y, which is physically the **right** of the gun.
> If you are cross-referencing the original Thingiverse files, swap L and R.

---

## Fusion browser

| component | holds |
|---|---|
| `00_Ref_PolarStar_F2` | the engine, bought-in model — shown, because it has to fit |
| `00_Ref_FCU` | FCU model |
| `00_Ref_Donor_Skins` | the original faceted skins, superseded |
| `00_Ref_Donor_Jacket` / `_Grip` / `_Meshes` | the rest of the donor geometry |
| `00_Ref_Import_Scrap` | dead duplicates left by the original import — safe to delete |
| `10_Steel_Core` | the tube |
| `11_Steel_Weldments` | everything welded to it, plus the EMT barrel |
| `20_Print_Receiver` | the receiver skins |
| `30_Print_Barrel` | jacket |
| `40_Print_Grip` | spade grips |
| `50_Print_Charging` | charging handle group |
| `60_Print_Trigger` | trigger group |
| `70_Print_Engine` | engine cradle |

Everything under `00_Ref` is hidden by default except the PolarStar, which stays
visible because the engine has to fit.

### Getting the browser into this order

**Fusion lists components in creation order, not alphabetically**, and there is no
API to reorder them — `Occurrence` has no index setter, and neither does anything
else. Numbering the names does nothing on its own; the `00_Ref` components were the
original ones and stayed scattered through the list at indices 0, 1, 4, 6, 8, 10 and 14
while the newer ones piled up at the bottom.

The only lever is creation order itself. `tools/reauthor/reorder.py` uses it:

1. rename every component out of the way (`~old~…`) to free the real names
2. create fresh components **in the order you want** — new ones append
3. `moveToComponent` the bodies across
4. delete the empties

It refuses to run if any component it would empty is not at an identity transform,
because moving a body out of a transformed component moves the geometry with it.
`00_Ref_FCU` *is* transformed and holds child occurrences rather than bodies, so it
is skipped and simply stays at the top.

Re-run it any time the order drifts. 58 bodies moved, 22 spot-checked for volume,
shell count and solidity afterwards — nothing shifted.

---

## Steel — cut and weld

Blue in the renders. Eleven pieces plus the tube.

| | part | cm³ | was called |
|:-:|---|---:|---|
|  | `ST-01-Core-Tube` | 344.50 | `CoreBox_cut` |
|  | `ST-02-Backplate` | 9.64 | `Backplate_1-8` |
|  | `ST-03-Backplate-Boss-L` | 3.24 | `BP_Boss_R_1-2` |
|  | `ST-03-Backplate-Boss-R` | 3.24 | `BP_Boss_L_1-2` |
|  | `ST-04-Barrel-Plate` | 16.04 | `Barrel_Plate_1-4` |
|  | `ST-05-Barrel-Socket` | 42.39 | `Barrel_Socket_1-5x156` |
|  | `ST-06-Cover-Spine` | 26.19 | `Hatch_Spine_1-8` |
|  | `ST-07-Hinge-Tab-L` | 5.55 | `Hinge_Tab_R_1-8` |
|  | `ST-07-Hinge-Tab-R` | 5.55 | `Hinge_Tab_L_1-8` |
|  | `ST-08-Pintle-Tab-L` | 26.25 | `Pintle_Tab_R_1-2` |
|  | `ST-08-Pintle-Tab-R` | 26.25 | `Pintle_Tab_L_1-2` |

## Hardware — buy

Brass in the renders.

| | part | what | was called |
|:-:|---|---|---|
|  | `HW-01-Barrel-EMT-1in` | 1" EMT conduit, the barrel | `Barrel_EMT_1in` |
|  | `HW-02-Switch-SS5GL13` | trigger microswitch | `REF_Switch_SS5GL13` |
|  | `HW-03-Trigger-Pin-4mm` | ⌀4 trigger pivot pin | `REF_PivotPin_4mm` |

## Printed

Light grey in the renders.

| | part | faces | cm³ | was called |
|:-:|---|---:|---:|---|
|  | `PR-11-Side-Rear-L` | 142 | 216.25 | `Side_R1` |
|  | `PR-12-Side-Rear-R` | 253 | 343.40 | `Side_L1` |
|  | `PR-13-Side-Front-L` | 71 | 131.75 | `Side_R2` |
|  | `PR-14-Side-Front-R` | 97 | 143.43 | `Side_L2` |
|  | `PR-15-Top-Deck` | 77 | 464.63 | `Top1` |
|  | `PR-16-Top-Cover` | 158 | 509.14 | `Hatch` |
|  | `PR-17-Front-Sight-Boss` | 254 | 106.40 | `FrontBoss` |
|  | `PR-18-Bottom-Rear` | 169 | 279.17 | `Bot1` |
|  | `PR-19-Bottom-Front-L` | 30 | 3.15 | half of `Bot2` |
|  | `PR-19-Bottom-Front-R` | 30 | 3.15 | half of `Bot2` |
|  | `PR-21-Barrel-Jacket` | 60 | 638.00 | `Barrel_Jacket` |
|  | `PR-31-Spade-Grips` | 1,549 | 330.82 | `Grip_Assembly` |
|  | `PR-41-CH-Handle` | 73 | 116.82 | `CH_Handle` |
|  | `PR-42-CH-Carrier` | 33 | 13.27 | `CH_Carrier` |
|  | `PR-43-CH-Shoe` | 8 | 3.96 | `CH_Shoe` |
|  | `PR-51-Trigger-Butterfly` | 611 | 32.78 | `Trigger` |
|  | `PR-52-Trigger-Switch-Carrier` | 52 | 23.10 | `Trigger_Switch_Carrier` |
|  | `PR-61-Engine-Cradle` | 30 | 181.08 | `Cradle_F2_HopUp` |

**18 printed parts, 3,540 cm³** — about 4.4 kg in PLA at 100% infill, considerably less
in practice. The rows above sum to 3540.30 and each one agrees with its STL; the
4.4 kg follows at 1.24 g/cm³.

> Do not hand-maintain this total. It has been wrong twice — 2,724 cm³ once, then
> 3,498 after the mating faces were flattened added 44 cm³ of fill. `tools/makepack.py`
> sums the table itself, so run it and copy what it prints.

`Bot2` was one body containing two disconnected rails; it is now two parts, which is
what a slicer would have made of it anyway.

---

## Files

```
stl/        one STL per part, named exactly as above — print straight from here
stl/donor/  the original donor meshes, kept for reference and attribution
cad/        one STEP per component group
```

Steel parts have STLs too. They are not for printing — they are for checking the
cut list and for anyone quoting the fabrication.

---

## Keeping it consistent

The build scripts in `tools/reauthor/` write directly into these components under
these names, so re-running a part does not undo the organisation. Two traps that
cost time when the model was reorganised:

- **`feature.bodies.item(0)` is wrong in a direct-design document.** It returns the
  component's *first* body, not the one the feature just made. That looks correct
  only while each part sits alone in its own component. Take the last body in the
  component instead.
- **Fusion hands back a fresh wrapper object on every access**, so `occurrence is
  target` is always False. Comparing identity instead of names silently hid every
  body and exported 29 empty STLs. Compare names.
- **Anything that looks a body up by name breaks on a rename.** The grip's relief
  cuts against the steel and the trigger were still searching for `CoreBox_cut` and
  `Trigger_Group`; they found nothing and quietly did nothing. Count what you match
  and print it.

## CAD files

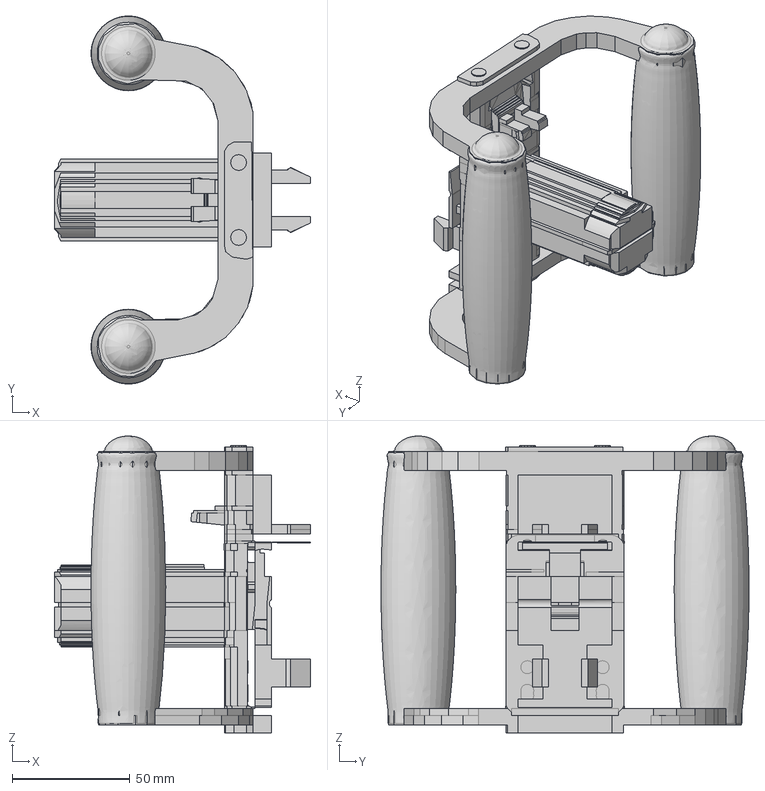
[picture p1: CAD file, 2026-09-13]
cad/Grip_Assembly_native.stp
108.7 x 156.2 x 126.0 mm

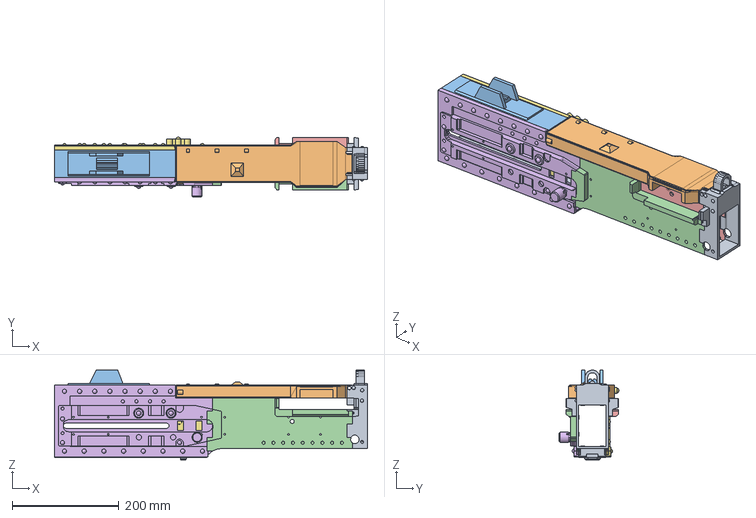
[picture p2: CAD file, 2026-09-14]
cad/20_Print_Receiver.stp
585.4 x 111.9 x 168.2 mm

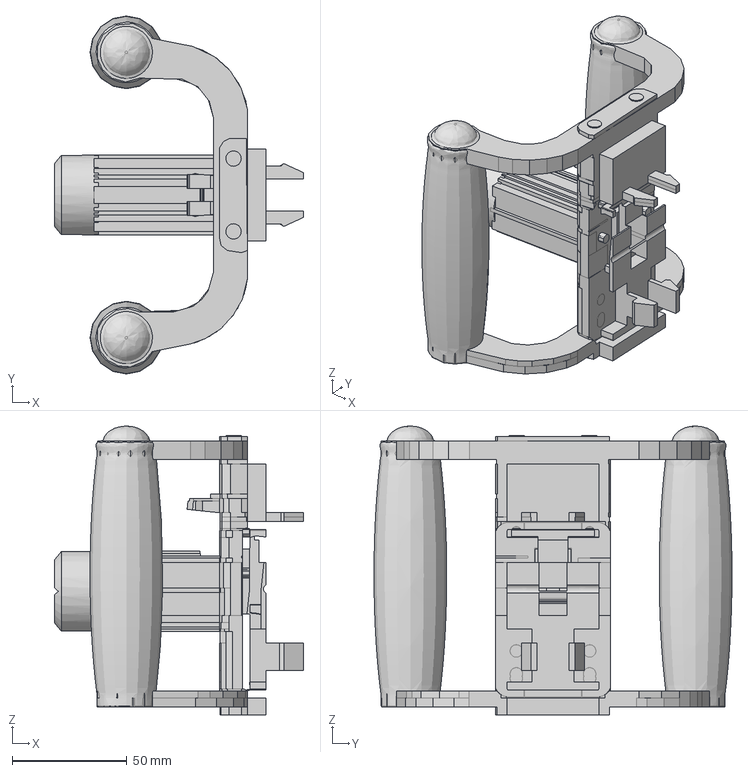
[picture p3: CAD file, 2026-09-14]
cad/40_Print_Grip.stp
108.7 x 156.2 x 126.0 mm

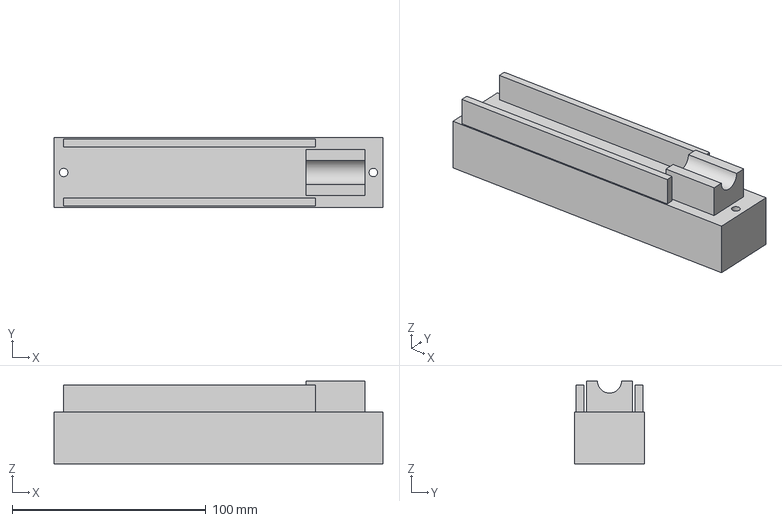
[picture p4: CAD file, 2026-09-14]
cad/70_Print_Engine.stp
170.0 x 36.0 x 42.9 mm

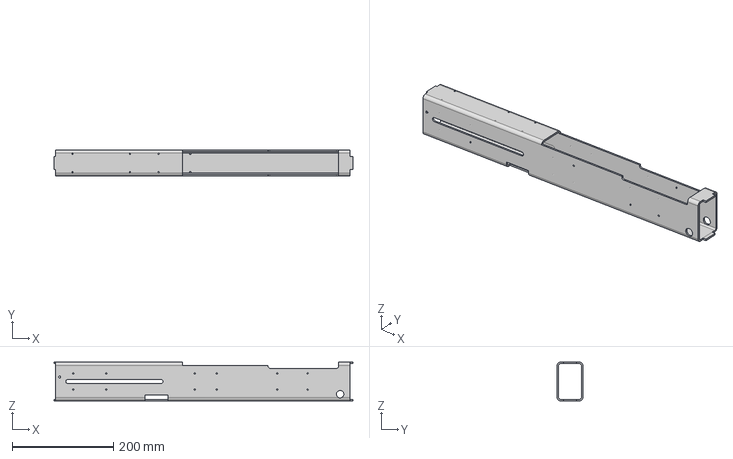
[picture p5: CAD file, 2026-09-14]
cad/10_Steel_Core.stp
589.5 x 50.8 x 76.2 mm

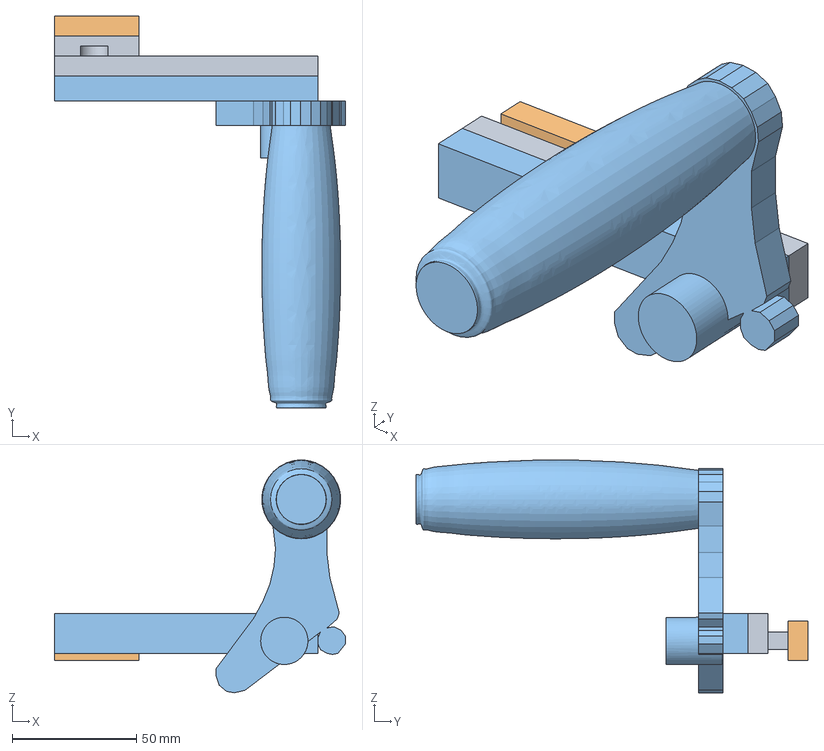
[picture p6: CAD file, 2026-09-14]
cad/50_Print_Charging.stp
117.0 x 157.4 x 93.5 mm

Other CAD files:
stl/donor/Grip_Assembly.stl
stl/donor/Barrel_Jacket.stl
stl/PR-16-Top-Cover.stl
stl/print-aids/PR-11-Side-Rear-L-ears.stl
stl/test/bed-level-squares.stl
stl/donor/Side_R2.stl
stl/PR-17-Front-Sight-Boss.stl
stl/print-aids/PR-12-Side-Rear-R-ears.stl
stl/donor/Side_L2.stl
stl/PR-13-Side-Front-L.stl
stl/donor/Side_L1.stl
stl/PR-12-Side-Rear-R.stl
cad/11_Steel_Weldments.stp
cad/30_Print_Barrel.stp
cad/60_Print_Trigger.stp
cad/Barrel_Jacket_native.stp
cad/M2_core_tube_RFQ.stp
cad/M2_steel_core.stp
source/M2_steel_core_design.f3d
stl/PR-11-Side-Rear-L.stl
stl/PR-14-Side-Front-R.stl
stl/PR-15-Top-Deck.stl
stl/PR-18-Bottom-Rear.stl
stl/PR-19-Bottom-Front-L.stl
stl/PR-19-Bottom-Front-R.stl
stl/PR-21-Barrel-Jacket.stl
stl/PR-31-Spade-Grips.stl
stl/PR-41-CH-Handle.stl
stl/PR-42-CH-Carrier.stl
stl/PR-43-CH-Shoe.stl
stl/PR-51-Trigger-Butterfly.stl
stl/PR-52-Trigger-Switch-Carrier.stl
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

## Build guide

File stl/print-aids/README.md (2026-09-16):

# Print aids

**Not design geometry.** These are the fitted parts with sacrificial pads added for bed
adhesion. Print these *instead of* the versions in `stl/`, then snap the pads off.

| file | |
|---|---|
| `PR-11-Side-Rear-L-ears.stl` | four ⌀20 × 0.6 mm mouse-ear pads at the contact-patch corners |
| `PR-12-Side-Rear-R-ears.stl` | the same |

Regenerate with `tools/reauthor/print_aids.py`.

## Why only these two

They are the 295.6 mm parts. PLA contracts about 0.4% as it cools, so each one is trying
to shrink **~1.2 mm along its length — 0.6 mm at each end** — and that force peels the end
corners off the bed. Nothing else in the set is both this long and this flat.

## Why not just a brim

The design sits at the bed limit on purpose: `BUILD-NOTES.md` puts the seam at X −265
because *"max forward is X −260.6 before Side_1 exceeds the 300 mm bed."* At 295.6 mm on a
300 mm bed there is **about 1.1 mm of margin at each end** — nowhere near enough for a brim
in the direction the part is actually contracting.

So the pads grow **sideways** instead. Across the part there is 165 mm of spare bed, so each
pad reaches 10 mm past the edge in Z while adding only 1 mm in X. It still resists the
lifting moment at the corner, which is the whole job. Added bond: **~157 mm² per corner,
6.3 cm² total.**

## Two things that will bite

**Footprint is 297.6 × 155.1 mm — 1.2 mm clear at each end on a 300 mm bed.** Centre it
properly. If the slicer nudges the part even 1.5 mm off centre, a pad is off the plate.

**Pad thickness is tied to layer height.** 0.6 mm is exactly two layers at 0.3 mm. A pad
thinner than one layer either vanishes at slice time or gets rounded up unpredictably, and
a single layer tears instead of snapping when you pull it. **If you change layer height,
change `PAD_T` and regenerate.**

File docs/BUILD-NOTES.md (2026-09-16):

# M2 Airsoft — Steel Core Conversion

Working notes for the Browning M2 airsoft build. Fusion doc:
`Browning_M2_0.50_cal_Machine_Gun_V.02-FS-R_-_corpus` in the **MaDuce** project.
Started 2026-09-09.

**Concept:** one simple structural box in steel — not printed — carrying all loads, with the
printed parts reduced to non-structural outer skins bolted/epoxied on, plus printed internals
holding the airsoft engine and hop-up.

---

## Coordinate system

**+X is forward (muzzle), −X rearward. Y = 0 / Z = 0 is the barrel axis.** All mm.

The source model is a **faceted STL conversion** — every face is planar, there are no analytic
cylinders, so bores cannot be snapped to and must be found by probing. Face counts 2.7k–11k per body.

---

## STEEL CUT LIST

Everything you cut and weld: the 2×3 tube plus eleven pieces.
*Everything you cut and weld: the 2×3 tube plus eleven pieces.*

| # | Part | Stock | Cut size | Qty | Wt |
|---|---|---|---|---|---|
| 1 | Core tube | 2" × 3" × 0.120" wall rect tube | 22-7/8" | 1 | 6.37 lb |
| 2 | Pintle tabs | 1/2" plate | 1.81" × 1.81" blank | 2 | 0.35 ea |
| 3 | Barrel front plate | 1/4" plate | 2" × 3" | 1 | 0.36 |
| 4 | Barrel socket | **1-1/2" OD × 0.156" wall round tube** | **4"** | 1 | 0.75 |
| 5 | Hatch spine | 1/8" × 1" flat bar | 13" | 1 | 0.45 |
| 6 | Hinge tabs | 1/8" plate | 0.87" × 3.56" blank | 2 | 0.10 ea |

**Total 8.75 lb steel.** Printed PLA ~2.6 lb. Finished ~14 lb with engine and hardware.
(Real M2HB is 84 lb; commercial airsoft M2s run 33–44 lb.)

### ALL STOCK MUST BE IMPERIAL
US steel supply. Never spec a metric size — work backwards from what's on the shelf.
Minimum practical purchase is a **12" length of any stock**.

### SHOPPING LIST (12" minimums, cut to length only — no rip cuts)

| # | Stock | Buy | Yields | For |
|---|---|---|---|---|
| 1 | 2" × 3" × 0.120" wall rect tube | 24" | 22-7/8" | Core tube |
| 2 | 1-1/2" OD × 1.188" ID DOM | 12" | 4" | Barrel socket |
| 3 | 1/2" × 2" flat bar | 12" | 2 × 1.81" | Pintle tabs |
| 4 | 1/4" × 3" flat bar | 12" | 1 × 2" | Barrel plate |
| 5 | 1/8" × 1" flat bar | 24" | 13" + 2 × 3.56" | Hatch spine + hinge tabs |
| 6 | 1/4" round bar | 12" | ~2.5" | Hinge pin |
| 7 | 1/2" round bar | 12" | ~2.5" | Pintle pin |
| 8 | 9/16" round bar *(or 9/16" grade-5 bolt)* | 12" | ~2.5" | Front mount pin |

Item 5 does double duty — spine and both hinge tabs come off one piece; the tab profile
(0.87" × 3.56") fits inside the 1" bar width. Widths are chosen so every part fits the bar with
no rip cut.

9/16" round bar is the least commonly stocked item; a grade-5 bolt substitutes fine. Do **not**
drop the front mount to 1/2" — that's 1.3mm of slop on a pin carrying the gun's weight.

### Pins
| Pin | Model bore | Use |
|---|---|---|
| Hinge | ⌀6.35 | 1/4", exact, ~2.5" long |
| Pintle | ⌀12.0 | open to 1/2" |
| Front mount | ⌀14.0 | 9/16" (14.29mm) |

---

## Core tube

2" × 3" × 0.120" wall, **X −560 … +20** (580mm / 22.83"). Centred at **Z −8**
(spans Z −46.1 … +30.1), Y ±25.4. **Interior 44.70 × 70.10mm.**

Dropped 8mm off-centre so the front mounting bore clears the floor by 3.05mm.
An initial 3"×3" pick was wrong — the receiver necks to 60mm wide in two places.

**Cut length 589.52mm (23.210").** Corner radii modelled: **R0.240" outside, R0.120" inside**.
Without them OSH Cut's profile matcher reads the section as aluminium extrusion — nothing in
their steel catalogue has square corners.

### Cuts in the tube
| Cut | Location |
|---|---|
| Top opening | X −310 … −2, **straight cut at Z +24, full width** |
| Belt slot | X −141 … −2, both walls, Z +18 up to the cut top edge |
| CH shaft slot | X −540 … −348 (192mm), Z −12 … −4, both walls, R4 |
| Air line | ⌀12.7 at X −410, bottom wall |
| Front mounting bore | ⌀14 at X +1, Z −33, both side walls |
| Pintle notches | X −384 … −338, both bottom corners, cut by the tabs themselves |
| Front locating tabs | X +20 … +26.35, top and bottom, 25mm wide |
| Rear locating tabs | X −563.18 … −560, top and bottom, 25mm wide |

The top opening **must** run forward to meet the belt slot at X −2. Stopping it short leaves a
cantilevered tongue ("a diving board").

**The top is one straight cut at Z +24** — the height where the corner radii begin, so it lands
flat on both side walls. No flanges, no R5 corners, no tab notches. The earlier flanged version
(Y ±19 with R5) fouled the hinge tabs and left messy geometry.

**Locating tabs are exactly their plate's thickness** so tab and plate faces finish flush —
nothing protrudes at either end. They pass through through-slots, keeping both the tube and the
plates laser-only. Blind pockets would be a milling op and were rejected.

---

## Weldments

The weldments in side view — tab positions along the tube.
*The weldments in side view — tab positions along the tube.*

- **Pintle tabs** ×2 — 1/2" plate, X −384…−338, Y ±15.7…28.4, **Z −92…−35**, ⌀12 bore at
  X −361 / Z −79. Tapered profile matching the printed lug (measured Y ±16…28).
  The top 11.1mm sits inside the tube and **cuts its own notch** through the bottom wall and up
  the corner, so the tab drops into a slot instead of balancing on the corner radius.
  Do not move them inboard — that was tried and rejected; it shifts the bore off the lug.
- **Hinge tabs** ×2 — 1/8" plate, **inside the tube** at Y ±19.18…22.35, X −22…0, Z −20…+70.5.
  22 × 40mm weld foot laps the inner side wall; neck tapers to an **r8 round head concentric
  with the pin** at X −9, Z +62.5. Round head = the hatch needs only a circular relief, so
  rotation is free by construction. **Line-drill the pin through both tabs after welding.**
- **Hatch spine** — 1/8" × 25mm × 329.9mm, inlaid into the hatch underside so hinge load never
  passes through plastic.
- **Barrel plate** — 1/4", welded across the tube end at X +20…+26.35, **bore ⌀38.9 (1-17/32")**
  plus two through-slots for the locating tabs. Leaves a 6.0mm web each side in Y.
- **Barrel socket** — 1-1/2" OD × 0.156" wall round tube, **X +13.65 … +113.65 (100mm)**.
  Only 6.35mm sits inside the tube; 87mm runs outside under the shroud.
- **Backplate** — 1/8", X −563.18 … −560, matching the tube's rounded profile, with two
  through-slots for the rear locating tabs. Basis for the trigger mount; bolt pattern TBD.

### Barrel = 1" EMT conduit, passing INSIDE the socket

EMT: OD 1.163" (29.54mm), wall 0.042", ID 1.079".
Socket 1-1/2" × 0.156": OD 38.10mm, **ID 30.18mm** → EMT passes through with **0.64mm**
diametral clearance. Up to **101mm of engagement**.

Printed boss ends at X +24.8, so the **EMT is the visible barrel from X +26.35 forward** and the
socket is hidden behind the skin.

#### Sourcing the socket
It is **round mechanical tubing, NOT pipe**. Pipe is sized by NPS and no pipe size lands near a
1.188" ID — that is exactly why 1" pipe won't take 1" EMT. Ask for it as
**"1-1/2 OD × 1.188 ID DOM"** (DOM is often called out OD × ID rather than by wall).

**Prefer DOM over HREW.** DOM is drawn over a mandrel so the bore is smooth and consistent, which
is what makes a 0.64mm slip fit actually slip. HREW has an internal weld bead that would bind the
EMT and need reaming.

| Spec | ID | EMT slop |
|---|---|---|
| 1.500 × 0.120 | 1.260" | 2.46mm — fallback, stocked everywhere |
| 1.500 × 0.134 | 1.232" | 1.75mm |
| **1.500 × 0.156** | **1.188"** | **0.64mm — spec'd** |
| 1.500 × 0.188 | 1.124" | **WON'T FIT** — EMT OD is 1.163" |

Going *thicker* fails outright. 0.156" (5/32") is a real standard wall but not the most commonly
stocked; 0.120" and 0.188" are more common. If 0.156 isn't available use **1.500 × 0.120** — with
~100mm of engagement the length controls concentricity far more than the clearance does, and the
rest can be taken up with three set screws at the muzzle end or a wrap of shim stock.
**Model change if switching to 0.120: socket ID 30.18 → 32.00; plate bore unchanged (OD is same).**

Rejected alternatives: 1" sch40 pipe of any schedule is **too small** (ID 1.049") — "1 inch" pipe
will not accept "1 inch" EMT. 1-1/4" sch40 has 5.5mm of slop. A 1" EMT set-screw coupling fits by
design but is usually zinc die-cast and won't weld. A 3/4" pipe spigot the EMT slides *over* was
built first (v54–v61) and replaced.

Verified: socket vs tube, cradle, hop-up and barrel all **0.000 cm³**.

Verified clearances: hinge tabs vs barrel, hop-up and tube all **0.000 cm³**.
Hatch rotation **0.000 cm³ through 75°**.

---

## Model landmarks (measured)

| Feature | Location |
|---|---|
| Receiver overall | X −560.6 … +24.8 |
| Floor within tube footprint | Z −50 |
| Belt feeding platform | Z +22.3, X −140.6 … −0.2 |
| Belt aperture, left wall | X −140 … −70, Z +25 … +40 |
| CH guide groove | Y ±24, X −544.2 … −325.8. Right side Z −13.0…+20.1 but **LEFT only Z −13.0…−2.9** — the band common to both is where the shaft slot belongs |
| Recessed side panel | Y ±20.3, X −292.1 … −148.6 |
| Hatch underside | Z +43.6 |
| Hatch hinge bracket | X −4 … +2, Z +59 … +66, Y ±30 — **FRONT of receiver** |
| Hatch central boss | Y −18 … +16 at X −12…−6 (what the pin passes through) |
| Front mounting bore | ⌀14 at X +1, Z −33, transverse (found at both Y ±27) |
| Pintle lug | two tabs Y ±16…±28, bore ⌀12 at X −361, Z −79, bottom Z −92 |

### Source bodies
`Receiver_Lower (1)` rear −560.6…−306.9 · `Receiver_Lower (1) (1) (1)` mid −334.3…−148.6 ·
`Receiver_Lower` front −148.6…+24.8 · `Hatch (1)` −334.3…−4.4

### Installed parts
- **PolarStar F2** X −239.9…−119.4, Y ±12.7, Z −16.0…+12.7
- **FCU** X −281.3…−226.7, Y ±10.8, Z +18…+25
- **HopUp** X −119.9…−89.4, on the barrel axis

### Traps that cost time
- The hatch lug at X −39…−29, Y ±41…45 has **no bore** — it's a latch flange. The hinge is at the front.
- The model contains **no charging handle mechanism** — only the guide groove above.
- `left`/`right` screenshot directions look **down the barrel** (the gun runs along X); use
  `front`/`back` for side views.
- Root `isBodiesFolderLightBulbOn` overrides individual body visibility.

---

> Every part rendered individually, with its catalogue name: **[PARTS.md](PARTS.md)**.

## SKIN FASTENING — 36 × M3 thread-forming into the tube wall

The nine printed receiver skins that bolt to the tube.
*The nine printed receiver skins that bolt to the tube.*
**The panels bed directly on the tube.** Every fastener has a ⌀3.4 clearance hole; the screw pulls
the panel's inner face flat against the steel wall, with no gap to bridge.

> **This used to be a 0.4mm clearance gap** (an artifact of what `ENV` creates) with a **⌀8 boss on
> the panel's inner face** at every fastener to bridge it — the reasoning being that a screw pulled
> across that gap would just flex a 3mm shell.
>
> **The inner face is the face these parts print on**, visible side up so the outside can be ironed.
> So each panel landed on the bed sitting on nothing but those bosses. Measured: `PR-13` rested on
> **2.46 cm² while 216.69 cm² floated 0.45mm above it** — and 2.46 cm² is exactly six bosses,
> 6 × (⌀8 disc − ⌀3.4 hole). 98% of the bed face was held in the air by six pads, and the slicer
> supported all of it.
>
> The gap is now filled instead (`tools/reauthor/flatten_mating.py`). The bosses are absorbed
> flush, the panel beds on the steel across its whole area — a better joint than six pads — and
> `tools/bedcheck.js` reports **92.7–99.9% of every bed face on the bed**. Verified 0.000 mm³ of
> penetration into the tube on all eight skins.
>
> The top and bottom strips had to follow: they ran to |Y| 25.80 to butt against panel faces at
> 25.85, so moving those faces to the tube wall at 25.40 made them overlap by 0.40 each side. They
> are trimmed to **|Y| 25.35**, keeping the original 0.05 clearance. A strip now spans the tube's
> full width and stops just shy of the panel beside it.

Tube gets **⌀2.65 pilot holes**; M3 thread-forming screws cut their own thread in the 0.120" wall.
No tap, no rivnut tool. Heads left proud — they read as the M2's rivet line.

| Panel | X positions | Z or Y |
|---|---|---|
| `PR-12-Side-Rear-R` `PR-11-Side-Rear-L` | −525.1, −460.1, −285.7 | Z −24, +8 |
| `PR-14-Side-Front-R` `PR-13-Side-Front-L` | −242.4, −122.9, −63.1 | Z −24, +8 |
| `PR-15-Top-Deck` | −526.7, −413.5, −356.9 | Y ±18 |
| `PR-18-Bottom-Rear` | −516.3, −442.4, −294.6 | Y ±18 |

Z −24 and +8 miss the CH slot (Z −12…−4) and the belt slot (Z ≥ +18); the X values miss the pivot
pin (X −552), the backplate bosses (X −560…−547), the pintle tabs (X −384…−338), the air line
(X −410) and the hinge tabs (X −22…0).

### Six interferences found while checking the above — now resolved

Pairwise-intersecting the eight skins against all 210 bodies turned these up. All four **predate
the mating-face work** — each was confirmed by checking that the overlap extends outside the
0.45 mm band that work added, so none of them is a consequence of it. They are small, and they are recorded here
because two of them looked like design questions rather than slips:

| | | |
|---|---|---|
| `PR-11-Side-Rear-L` ↔ `PR-13-Side-Front-L` | 34.6 mm³ | the lengthwise seam at X −265; the two panels overlap X −275…−265 |
| `PR-12-Side-Rear-R` ↔ `PR-14-Side-Front-R` | 37.6 mm³ | the same seam, other side |
| `PR-12-Side-Rear-R` ↔ `HW-03-Trigger-Pin-4mm` | 20.1 mm³ | the panel fouls the ⌀4 pivot pin — **this one blocks assembly** |
| `PR-15-Top-Deck` ↔ `PR-31-Spade-Grips` | 6.6 mm³ | deck corner into the grip spine |
| `PR-17-Front-Sight-Boss` ↔ `ST-07-Hinge-Tab-L` | 12.6 mm³ | **printed part sits down over welded steel** |
| `PR-17-Front-Sight-Boss` ↔ `ST-07-Hinge-Tab-R` | 2.9 mm³ | the same, other side |

**All four are cleared** by `tools/reauthor/resolve_clashes.py`, at 0.20 mm — deliberately more than
the 0.05 between a strip and a panel, because these are not faces meant to bed together but places
where two parts occupied the same space, and a printed joint wants room to be slid into.

"It is probably an intentional lap" turned out not to be a defence. Two solids cannot share space
whatever the intent; a lap still needs the clearance cut into one side of it. The part that gives
way is the one easier to reprint and less load-bearing — the front panel yields to the rear, the
skin yields to the hardware. Each cut leaves **0.000 mm³** of overlap and a single shell, and the
bed faces are untouched: every relieved area became a pocket deeper than 1 mm, so bed contact stayed
at 92.7–99.9%.

**The last two were only found when the check was widened from the eight skins to all eighteen
printed parts.** The first four came out of checking the parts that had just been edited, which is
the natural thing to do and is why the front sight boss — untouched for days, and previously
reported clear — went unexamined. It runs back to X −13.4 while the hinge tabs run forward to X 0,
so it was sitting down over both of them. Welded steel does not yield; the printed part does.

The check that now stands is the whole matrix: **all 18 printed parts against all 210 bodies, 0
clashing pairs**, deepest penetration into the tube 0.0000 mm³, 18 of 18 single-shell solids.

**`PR-19-Bottom-Front-L` / `-R` cannot be screwed** — two rails over the tube's bottom corner radii with no flat behind
them (tube reads 0.016 cm³ against a ⌀5 probe where the panel is solid). Bond it.

**Probing the top panel: the tube's top is at Z 27.05…30.10 over X −560…−310.** Probing at the
Z +24 cut line reports zero viable positions, because the cut only exists from X −310 forward.

## CLEARANCE: where printed parts meet welded steel

Measured by inflating each steel body until it touches the printed part. **19 interfaces
sit under 0.20 mm.** They are two different things and only one of them is a problem:

**Face bedding — 0.00 mm is correct.** The printed face lies flat *on* steel. Thin in
exactly one axis.

| `PR-11` → tube | 295.00 × 0.60 × 69.28 |
|---|---|
| `PR-15` → cover spine | 0.60 × 25.00 × 3.18 |
| `PR-52` → backplate | 0.60 × 40.00 × 39.50 |

**Enveloping fits — 0.00 mm is unbuildable.** Printed material wraps *around* steel, so
it needs room for FDM tolerance and weld distortion both.

| | extents | clearance |
|---|---|---|
| `PR-11` → pintle tab | 47.20 × 3.55 × 32.50 | ≤ 0.02 mm |
| `PR-18` → pintle tab | 47.20 × 10.30 × 20.85 | ≤ 0.02 mm |
| `PR-16` → cover spine | 329.90 × 26.20 × 3.72 | ≤ 0.10 mm — **fixed, now 0.50** |
| `PR-31` → trigger pin | 1.60 × 40.00 × 4.66 | ≤ 0.02 mm |
| `PR-51` → trigger pin | 5.20 × 12.00 × 5.20 | ≤ 0.15 mm |

Only the spine was corrected in CAD, because a 329.9 mm steel bar will not enter a
printed slot at 0.10 mm by any means. The rest are **hand-fit at assembly**:

- **Pintle pockets** — `PR-11`, `PR-12`, `PR-18` printed unsupported, so the bridge over
  each pocket sagged *into* it. At 0.02 mm nominal any droop fouls the tab. Check with a
  straightedge and dress flat before assembly.
- **Trigger pin bores** — ream to size after printing. An FDM hole comes out undersize
  anyway, so opening the model risks a sloppy pivot instead of a tight one.

**Never put support material in an enveloping fit.** It has no clearance to give up.

## PRINTED SKIN RULES

**"Flat panels" means flat FOR PRINTING, not featureless.** Each piece lies flat on the bed with
its visible face UP so the top surface can be **ironed**. All M2 surface detail must survive.
Clean native plates with no detail were tried and rejected outright.

**Sides are full-height flat panels, cut on the TUBE WALL planes (Y ±25.8).** Left = Y ≤ −25.8,
right = Y ≥ +25.8, top to bottom. **Do not wrap the sides around the bottom.**

**Top and bottom are strips that fit BETWEEN the side panels** — the 51.6mm middle zone, above
the tube top (Z ≥ +30.5) and below the tube bottom (Z ≤ −46.5).

**Two lengthwise sections, not three.** The front boss is a separate part and doesn't count.

**Seam at X −265.** As far forward as the bed allows so the charging-handle geometry (groove ends
X −325.8) is well clear. **Max forward is X −260.6** before Side_1 exceeds the 300mm bed. The
Y ±20.3 recessed panel does get crossed; that's accepted — clearing the CH geometry matters more.

**Bed is 300mm (Creality K1 Max).** The hatch at 329.9mm only fits laid diagonally
(294mm footprint, 5.7mm margin).

### Alignment: interlocking finger seams, NOT dowels
**The panels are a ~3mm shell, not solid.** Dowels were tried and failed — a 3.2mm hole in a 3mm
wall breaks through both faces and is visible from outside. Placement tests must check a full
**envelope** around a hole, not just two points along its axis.

Current scheme: **2 fingers per side per seam, 10mm deep**, on the side panels only, projecting
from section 2 into its neighbours. Alignment lives in the seam plane so nothing shows outside.
The top/bottom strips are too thin (3–8mm) for fingers — they keep plain butt seams and need
clamping during glue-up.

### DONOR MESHES — check `isSolid`, not just that a boolean returned
`grip.stl` converts to a **surface** body, not a solid, because the mesh is not watertight.
A boolean against an open surface returns "no interference" **no matter what** — there is no
inside for it to find. That silently passed a clash check that was hiding 25.7 cm³ of overlap.
**Always print `body.isSolid` after a mesh convert.**

Repair with `tools/meshrepair.js`. The grip's defect was **T-junctions, not holes**: 8 open edges
whose four "loop" vertices are collinear (same X, same Z, varying Y only) — one side of a seam
used a single 66.6mm edge while the other used three shorter ones. Capping a zero-area loop with a
centroid fan just produces degenerate triangles, which is what a naive hole-filler does. The fix is
to **split the long edge** at the intruding vertices. 4 splits closed it; volume unchanged at
304.6 cm³.

The donor grip **includes its own backplate** — it overlapped the steel `ST-02-Backplate` by
9.04 cm³ over the full height, because on a real M2 the backplate is part of the grip assembly.
The printed grip is relieved around the steel (−25.7 cm³) exactly as the skins are: steel carries
load, plastic is cosmetic. The buffer tube is relieved for the trigger arm's swept envelope
(−1.5 cm³).

**Relieve against the SWEPT envelope of moving parts**, not their rest position — the trigger
envelope over 0…5.5° is 43.0 cm³.

### BACKPLATE IS BOLTED, NOT WELDED
Welding it seals the trigger away for good — the mechanism is at X −580…−526 and the tube's top
opening only runs X −310…−2, so there is no other way in.

**4 × M5 at Y ±16, Z −26 and Z −36**, into two 1/2" bars welded down the inside of the rear walls
(`BP_Boss_L/R_1-2`, X −560…−547.3, Z −39…−17). 12.7mm of thread depth.

**The bars must stop at Z −39.** Running them to −43 clips the tube's interior corner radius,
which begins at Z −39.9 (0.023 cm³ each).

**All four screws are low** — Y ±16 spread 32mm, but only 12mm apart in Z. The switch carrier
occupies Y ±22, Z −16…+26.8 and blocks every upper position. The top of the plate is held by the
rear locating tab instead. Freeing an upper pair would mean trimming the carrier's flange, which
risks disconnecting it from the wall rails at Z 13…23.5.

**The pivot pin cannot retain the backplate** — pin at X −552, backplate at X −563.18…−560, 8mm
apart and never intersecting. What the pin *does* need is drift access: a **⌀6 hole in `PR-11-Side-Rear-L`
at X −552, Z +1**, otherwise the side skin traps it.

Disassembly, each step verified by sweeping the part clear of everything:
1. drift the pin out through the `PR-11-Side-Rear-L` hole
2. draw the trigger straight back, lever sliding out through the backplate slot
3. undo 4 × M5 — the backplate lifts off and brings the switch carrier with it

### TRIGGER — press DOWN, tail rises, switch sits ABOVE the tail

Butterfly, switch carrier, microswitch and the ⌀4 pin. The switch sits ABOVE the tail.
*Butterfly, switch carrier, microswitch and the ⌀4 pin. The switch sits ABOVE the tail.*
**Direction matters and I got it backwards once.** Pressing the butterfly down at the rear swings
the tail *up*, because the press point is behind and above the pivot. The switch therefore sits
**above** the tail, not below it. If the switch is under the tail the mechanism can never fire.

Switch is an **Omron SS-5GL13** — subminiature, simulated roller lever. Body 19.8 × 10.2 × 6.4mm,
mounting holes ⌀1.6 at 9.5mm pitch, **OT min 1.0mm, OF 50gf**. The lever type was chosen
deliberately: a bare plunger only tolerates a few tenths of overtravel and the striker would
bottom on the switch body.

Geometry: pivot X −552 **Z +1**, lever run Z −6…+8, striker on top of the lever at X −540 rising
to Z +10.0, switch actuator free at Z +10.4 (**0.4mm gap**), body Z +10.4…+20.6.

  5.0 deg -> presses 0.65mm   FIRES
  5.5 deg -> presses 0.75mm   hard stop engages, inside the 1.0mm OT

**`PR-52-Trigger-Switch-Carrier` registers off the tube itself**, so the switch lands in the right place
without measuring: a narrow ceiling pad at Y ±18 bearing on the interior roof (**measured at
Z +27.0**, not the +20.95 I first assumed — the rear of the tube is uncut), and wide rails at
Y ±22.0 on the flat part of the side walls. **The pad must be narrower than the rails** — the
interior corner radii pull the width in to ±20.38 by Z +26.8, so a full-width roof clashes.

Slides in from the rear before the backplate is welded; also bolts through 2 × M4 at Y ±16, Z −8.

**Fusion joints are not available here** — `AsBuiltJointInput is only supported in parametric`,
and this document is direct-modelling with no timeline. Motion has to be verified by transforming
a copy and running boolean intersections, which is what every check above does.

### Superseded trigger designs — do not revisit
The F2 is electronic, so the trigger only has to close a microswitch. **The switch does not need
to be inside the tube — only its wires do.**

**Pivot is a ⌀4.2 pin through BOTH tube side walls at X −552, Z +6.** Anchoring in the steel beats
any bracket, and it puts the spring inside where there is room.

- `PR-51-Trigger-Butterfly` — the donor butterfly plus an integral lever: a drop behind the backplate
  (X −578…−569, Z +2…+30) then a run forward through the backplate (X −572…−534, Z +2…+10).
  Pivot bore at X −552 Z +6, ⌀3 peg hole in the tail at X −534 for the return spring.
- `Trigger_Switch_Mount` — printed, bolts to the backplate's inner face with the 2 × M4 at
  Y ±16 Z +8. Holds a microswitch under the tail at X −540, Z −6, plunger up.
- Backplate carries a **16 × 15mm lever slot** at Y 0, Z −2…+13.

Lever ratio: thumb radius 51mm, tail radius 18mm. **6° of trigger travel = 5.33mm at the thumb
and 1.88mm at the tail** — a D2F needs ~0.5mm, so 2–3° is enough to fire. Return is a torsion
spring on the pivot pin; the ⌀3 tail peg is the alternative anchor for a tension spring.

Verified clear of tube, backplate and switch mount through 10°.

**Two rejected versions, do not go back to them:**
1. A 27mm slab arm hanging off the trigger with a ⌀7 boss poking through the backplate into the
   tube, plus two welded steel ears for the pivot. Clunky, and the boss bound in its hole as it
   tilted through the arc.
2. Pivoting on a printed bracket bolted behind the backplate, switch outside. Tidier, but the
   pivot was in plastic and there was nowhere good for a spring.

**The switch mount's flange must be split either side of the lever's Y ±6 channel** or it fouls
the lever at rest (0.096 cm³).

### BARREL — EMT is the barrel, only the jacket is printed
**Do not print the barrel.** 1" EMT conduit (⌀29.54) *is* the barrel, running X 13.65 (bottomed
in the socket) to X 1010.5 — 996.9mm / 39-1/4", 2.49 lb. Socket ID 30.18 gives 0.64mm diametral
clearance over the full 100mm of engagement.

**The perforated jacket IS printed** — it is the M2's identifying feature. X 26.75…287 (260.2mm),
bored ⌀38.90 over the socket and ⌀30.20 for the EMT, with a centring ring at X 274…284 so it
can't flop on the conduit. Fits a 300mm bed stood on end (+X up, 9.3% overhang).

The jacket-to-thin-barrel step is at **X ≈ 285**; X 285…298 is a smooth prismatic zone with no
vertices, which is why it cuts cleanly there.

**The jacket's rear runs to X 24.80, not 26.75.** Trimming it to the barrel plate's front face
(26.35) + 0.4 left a **1.95mm gap** to `PR-17-Front-Sight-Boss`, which ends at X 24.80 — the 1/4" plate showed
through all the way round. **Trim the jacket to PR-17-Front-Sight-Boss, not to the plate.**

To extend it: the jacket's section is **constant over X 26.75…29.00** (2.235 cm³ at every slice),
so take a 1.95mm slice and translate it back — an exact extrusion without needing a sketch. Then
pocket it Y ±25.8, Z −46.5…30.5 to clear the plate. Adds 4.47 cm³.

**Bond the joint, don't bolt it.** The butt gives **1,615 mm² of contact** (70% of the jacket's
2,295 mm² rear face — `PR-17-Front-Sight-Boss` is only Y ±30 against the jacket's Y ±39.6, so they don't fully
overlap). That is several times what epoxy needs, and the ⌀38.90 bore over the socket already
locates it radially across 87mm. 23 bolt positions were found viable in the top band, but **every
one is unreachable once assembled** — 260mm of jacket in front, 38mm of PR-17-Front-Sight-Boss behind.

EMT is galvanised: etch-prime before paint, and never weld or braze it (zinc fumes). It doesn't
need welding — it's a slip fit.

The socket leaves **88.8mm exposed** ahead of the front skin. It was positioned forward when a
full-length printed shroud was going to hide it; the jacket now covers it, so that is moot.

### CHARGING HANDLE — slide + spring return, 150mm travel, IN THE EXISTING SLOT

Handle, carrier and shoe. The carrier sandwiches the tube wall through the existing slot.
*Handle, carrier and shoe. The carrier sandwiches the tube wall through the existing slot.*
**Design the carrier to fit the slot; do not enlarge the slot to fit the donor part.** The
upstream `charging.stl` has a shoe 17.6mm tall, and I once cut a 214 × 19mm aperture in the left
wall to pass it. That was wrong — the donor shoe is discarded anyway (the handle bolts to a
carrier we make), so the neck can be any size we like. It removed 4066mm² where 2032mm² does, and
forced an RFQ change for nothing. Reverted.

Track = **the existing 192 × 8mm slot**, X −540…−348, Z −12…−4, both walls, R4 ends. Straight
section is X −536…−352 = 184mm. Neck 34mm + 150mm travel = 184mm, an exact fit.

**No guide rod. No shaft. Three printed parts sandwich the wall and the slot is the track.**
An earlier version had a 1/4" rod on two welded tabs — deleted, it was a complicated part for no
benefit and cost 0.128 lb of steel and two weldments.

- `PR-43-CH-Shoe`    X −386…−352, **Y −22…−14**, Z −16…0 — inside the tube, 16mm tall behind an 8mm
               slot so it cannot pull out. 2 × M4 heat-set inserts.
- `PR-42-CH-Carrier` neck Y −30…−22, **Z −11.5…−4.5 (7mm in an 8mm slot)**; pad X −386…**−280**,
               Y −38…−30, Z −13…+3. 2 × M4 clearance to the shoe, 4 × M6 clearance to the handle.
- `PR-41-CH-Handle`  donor arm outboard of Y −48, unioned to a **full-length foot** X −386…−280,
               Y −48…−38, Z −13…+3. **4 × M6 heat-set inserts in the foot.**

Clamped stack is skin-outer-face (Y −30.0) to tube-inner-face (Y −22.35) = **7.65mm**, neck spans
8.0mm → **0.35mm running clearance**. Do not "fix" the neck to 7.65.

Mating area handle-to-carrier is **1696 mm²** of flat contact. The earlier 2 × ⌀14 boss joint was
replaced because it only touched at two spots and M4 was too small.

**Assembly order:** bolt handle to carrier off the gun (M6 heads sit in counterbores on the pad's
inner face and are unreachable once fitted) → offer the pair to the slot → turn the shoe 90° about
X so its 8mm edge is vertical, pass it through the slot, rotate home → 2 × M4.

### The pad must cantilever forward — the slot and the handle do not line up
Two measured facts that force the design:
- **`PR-12-Side-Rear-R` is open only over X −540…−350.** Forward of that the panel is solid, so the neck
  cannot go forward — it has to stay inside that window.
- **The donor handle only has material to bolt into over X −320…−262** (probe Y −70…−46). Its
  arm root is forward of the panel opening entirely.

So the neck sits at X −386…−352 and the **pad cantilevers 106mm forward to X −280** to reach the
handle. Do not try to move the slot forward to meet the handle: moving it 28mm forward put the
neck into solid panel (0.466 cm³) and the bolts still had nothing to bite. Reverted.

Joint: **2 × M6** through the handle into heat-set inserts (⌀8.0 × 9mm) in ⌀14 bosses on the pad
at **X −306 and −286**, the bosses registering in ⌀14.4 pockets in the handle so the joint is
located as well as clamped. M4 was too small. Confirmed 0.92 and 1.14 cm³ of handle material
behind each boss — check this, because most of the pad's length has nothing behind it.

Trimming the donor at Y −38 leaves a **0.286 cm³ loose fragment** at X −360…−351; delete it or the
STL exports as two shells.

**The pad's top must not exceed Z +3.** The left skin's outer surface steps outboard above
Z ≈ +3.3; a pad reaching Z +4 buries 0.7mm into the panel at every stroke position.

**The skin already has the slot.** `PR-12-Side-Rear-R` is open over the slot footprint — the corpus models
it as a through-feature, so no channel needs cutting. Verify rather than assume: a cut that
removes 0.00 cm³ means either it was already open or the boolean silently failed.

**Sweep against the SKINS too, not just tube + weldments.** The first travel check omitted them
and missed a standing 0.071 cm³ interference at every position.

**The return is shock cord, not a steel spring.** 150mm of travel needs a ~350mm compression
spring; there is only 230mm of clear tube behind the carrier. Route the cord at **Y −20, Z −30**:
clear of the cradle (reaches Y −18), the F2 (Y ±12.7), the hinge tab (Z −20 up) and the pintle
tabs (Z −35 down). That is the only end-to-end clear path.

### THE DONOR PARTS ARE STILL FACETED — and cannot be converted automatically
11 bodies are faceted STL conversions totalling **67,497 faces**. Everything designed
from scratch is native: the tube is 135 faces with 73 real cylinders, the weldments are
4-32 faces each. So **the STEP a fabricator receives is clean** — only the cosmetic
printed parts are faceted, and those ship as STL anyway.

| | bodies | faces |
|---|---|---|
| faceted (donor-derived) | 11 | 67,497 |
| native (designed here) | 26 | ~900 |

**Do not waste time on `PrismaticMeshConvertMethodType`.** Tested exhaustively against
`FacetedMeshConvertMethodType`:

- Prismatic with no face groups -> identical output
- Prismatic + `meshGenerateFaceGroupsFeatures`, Fast (29 groups) -> identical output
- Prismatic + face groups, **Accurate** (36 groups) -> identical output

592 faces, all planar, zero cylinders, every time — on both a 592-face trigger and a
20,730-face barrel. Fusion generates the face groups correctly and the convert ignores
them. Prismatic almost certainly requires the **Product Design Extension**, which the
docs only flag for Organic.

Two API traps found on the way: `meshGenerateFaceGroupsFeatures.createInput()` takes a
**single MeshBody, not a list**, and the method property is
`meshGenerateFaceGroupsMethodType` (0 = Fast, 1 = Accurate) — a wrong name silently
swallowed by a bare `except` leaves it on Fast.

**Rebuilding these means re-authoring the M2's panel and rivet detail by hand.** That is
not a conversion, it is modelling a new part, and the result would no longer be
HappyBattleSheep's artwork — which is the whole point of the skins. Worth doing only to
change the surface detail or to drive the panels parametrically.

### Fusion gotchas learned here
- **An exception anywhere in a script rolls back everything that script did.** A mesh convert that
  succeeded was silently undone by a trailing `isLightBulbOn` error on the consumed mesh. Wrap
  `main()` in try/except and print the traceback instead of letting it propagate.
- **`exportManager` body-level STL export can report `execute=True` and write nothing.** It failed
  on the 20k-face barrel at every refinement level. Export the **occurrence or component** with
  everything else hidden instead, and always stat the file afterwards.
- Mesh → BRep: `component.features.meshConvertFeatures` with
  `FacetedMeshConvertMethodType`. ~5s for 20k triangles. In a direct-design doc `add()` returns
  null but the conversion still happens; find the new body by name.

### Pin bores are sized to IMPERIAL bar, not round metric
US bar stock is 6.35 / 12.70 / 14.29 mm — a ⌀12 bore will not take a 1/2" pin. Every pin bore is
cut **0.30 mm over nominal bar**: hinge ⌀6.65 (1/4"), pintle ⌀13.0 (1/2"), front mount ⌀14.6
(9/16"). Do not round these back to 12/14/6.

**When auditing bores, check the face AXIS and AREA, not just the diameter.** The tube's A500
corner radii show up as cylindrical faces at ⌀12.19 (R0.240" outside) and ⌀6.10 (R0.120" inside),
running lengthwise along X with face areas in the thousands of mm². They are fillets, not holes.
Reading them as bores produced a false "three bores are wrong" report; only two actually were.
Real pin bores run along **Y**, are short, and have face areas under ~500 mm².

### Standing subtractions — IN THE GENERATOR, not by hand
Manual deletions "keep coming back" because regenerating from source discards them.
- **Tube clearance envelope `ENV`**: `bx(-26.85, 0, -0.80, 59.1, 5.16, 7.70)` — X −564…+27,
  Y ±25.8, Z −46.5…+30.5. **It must span the WHOLE tube including the locating tabs at both
  ends**, not just the tube body. It was X −561…+21 while the front tabs reached X +26.35, and
  the ~5mm of tab past the envelope drove PR-17-Front-Sight-Boss into the steel by 0.5795 cm³.
  **Whenever the tube's extents change, ENV changes with them** — query
  `tube.boundingBox` and check it rather than assuming.
- **Feed way**: no skin material above the tube in X −334.3 … −13.3. Deletes `Top2` entirely and
  ends `PR-15-Top-Deck` at X −334.3 — the top deck only exists *behind* the hatch.
- **Pintle lug**: X −395 … −325, everything **below Z −67**. The steel tabs are the lug.
  Cut only below −67, not −50 — the shoulder Z −50…−67 is real side-panel geometry.
- **Front trim**: X 26…41, Y ±14, Z −36…−22 — strands left forward of the barrel plate.
- **Front ring trim**: cylinder r19.8 on the barrel axis, X +19.5…+27.0. Removes two floating
  concentric rings (r15.1 and r19.4) left in PR-17-Front-Sight-Boss when the socket bore went through.
  Socket OD is r19.05, so the trim clears the steel by 0.75mm.
- **Pin bore**: ⌀6.35 at X −9, Z +62.5 cut from **every** skin so one pin passes through
  PR-17-Front-Sight-Boss lug → tab → hatch boss → tab → PR-17-Front-Sight-Boss lug.

**Every piece must be a single shell, and volume must conserve.** Always print
`sum of parts == union volume, LOST 0.00`. A silent bug once dropped the receiver's top shoulders
entirely — the region `{|Y|>25.8, Z>38.5}` belonged to no piece and vanished.

---

## Fusion MCP workflow

- **Never point-probe at high resolution.** `pointContainment` on an 11k-face body hangs Fusion's
  UI thread for 20+ minutes. Budget a few hundred probes. `TemporaryBRepManager` booleans are
  ~0.03s even on faceted bodies — use those freely.
- **Prefer face queries over sampling** to locate features. Iterating `body.faces` filtered by
  `surfaceType == PlaneSurfaceType` plus normal direction is instant and exact. Mesh-node binning
  misled badly twice — put the belt notch 100mm off and reported the receiver floor 7mm high.
- **Fusion rolls back the entire script on an exception.** A late failure discards earlier edits.
- **Verify saves by re-reading geometry.** A save reported success, Fusion crashed, and recovery
  came back *behind* it, silently losing two edits.
- **Sketch on the XZ plane maps sketch-Y to world −Z.** Negate or the part comes out mirrored.
- **`booleanOperation` returns a bool**, not a body. `b = tbm.booleanOperation(b, x, UNION) or b`
  assigns `True` and the next call throws TypeError. Bit me twice.
- **Cutting coincident with a planar face makes zero-thickness shells.** Offset ~0.05mm.
- **Direct-design docs have no `snapshots`** — touching `des.snapshots` throws.
- **The stuck-mouse bug is Deskflow**, not Fusion and not WhisperFlow. It loses the button-up
  event on screen transitions so Fusion orbits forever. Click the button once in the viewport.

---

## Print orientation — a real tension

`tools/stlcheck.js` reports overhang burden per orientation. Standing the pieces **on end**
collapses it, but puts the visible face vertical where it cannot be ironed:

| Piece | Flat (+Z up, ironable) | On end (min support) |
|---|---|---|
| Hatch | 33.6% | 4.2% |
| PR-18-Bottom-Rear | 31.7% | 3.4% |
| PR-15-Top-Deck | 22.0% | 4.6% |
| PR-19-Bottom-Front | 21.3% | 0.4% |
| PR-12-Side-Rear-R | 11.3% | 2.3% |

Flat-and-ironable is the chosen orientation; the cost is 20–30% of surface needing support on
several pieces. All parts pass watertight with correct normals and 1 shell (PR-19-Bottom-Front's two
rails, left deliberately).

## Still open

1. **Skin-to-tube fastening** — no bolt bosses, holes or captive nuts anywhere. Biggest gap.
2. **Rear closure** — tube's back end at X −560 is open. No backplate, grips or trigger.
3. **Verify the three inferred pin positions** against real hardware before drilling steel.
4. **CH slot width** — the 8mm is a guess, not measured. Carrier/handle not modelled.
5. **Torsion cross-strap** over the 139mm U-channel run (top + both walls cut).
6. `PR-19-Bottom-Front` was 2 shells (two bottom rails) and is now split into `-L` and `-R`.
7. Hatch latch, feed tray detail.
8. Deliverables not produced: 1:1 plotter template (single sheet, not tiled), STL exports.

## REMOVABLE BARREL — M5 set screws in the socket

Socket welded to the front plate; the 1" EMT drops in and is held by two set screws.
*Socket welded to the front plate; the 1" EMT drops in and is held by two set screws.*
The socket is **welded to the barrel plate**, so it is fixed and can be tapped. Wall is
(38.10 − 30.18)/2 = **3.96mm**, enough for full M5 thread.

- 2 × M5 tapped **at X 55 and X 75**, entering from underneath (tap drill ⌀4.2, Z −21…−15.05)
- **Stop the tap hole at Z −15.05.** The socket ID is r15.09 and the EMT OD r14.77; drilling past
  −15.05 cuts the EMT instead of leaving the screw to press on it.
- The screws close a **0.32mm radial gap**. Dimple the EMT at both positions so they locate
  positively instead of relying on friction.

**X 95 lands on one of the jacket's cooling holes** — the jacket has no material underneath there.
X 55 and 75 are solid.

The screws are buried under the jacket, so the jacket gets **2 × ⌀7 access channels** straight up
from its underside at the same X. Verified a 3.0mm driver shaft runs clear through jacket, socket
and EMT to reach both screws with everything assembled. Barrel then slides straight out forward —
swept 150mm, no catch.

The jacket itself stays bonded to `PR-17-Front-Sight-Boss`; it never has to come off to change the barrel.

## NATIVE REAUTHORING — proven on the barrel jacket
`PR-21-Barrel-Jacket` is authored from primitives, not converted from mesh.

| | faceted | native |
|---|---|---|
| faces | 17,422 | **57** (13 planar, 39 cylindrical, 5 conical) |
| STEP | ~1 MB | 382 KB |
| editable | no | hole count, diameter, pitch and profile are all variables |

**305x fewer faces**, and it is real analytic geometry — the holes are true cylinders, the
flanges true cones.

### How the pattern was measured
Vertex-occupancy does not work: a smooth cylindrical band has vertices only at its edges, so
empty bins read as holes. Two wrong answers came out of that before ray-casting gave the truth.

**Ray-cast inward from r=60 on an (x, theta) grid and record the FIRST-hit radius.** Hit near
r=39.6 means wall; anything deeper means a hole. Counting hits alone is useless — every ray
crosses the far wall, so everything reads as material.

Measured result: **4 holes per row at 90 degrees, alternate rows offset 45 degrees**, pitch
25.5mm, 7 rows from X 88, d26. Staggered, not aligned — an earlier read said 8 aligned rows of
d20 and looked visibly wrong against the donor.

### Profile, measured off the donor
Rear flange r50.80 to X 38, taper to r41.35 by X 41, r41.35 to X 82, taper to r39.60 by X 90,
main tube r39.60 to X 272, muzzle flange r41.40 X 272..284. Bore r19.45 over the socket to X 46,
then r29.13; centring ring r15.10 at X 273..285.

**Do not forget the barrel-plate pocket** (Y +/-25.8, Z -46.5..30.5 over X 24.3..26.75). Without
it the native jacket fouls `ST-04-Barrel-Plate` by 3.9 cm3.

### What is NOT worth reauthoring
The jacket worked because it is a body of revolution with a regular hole pattern. The rest are
not:

- `PR-31-Spade-Grips` (17,621), `PR-41-CH-Handle` (10,134) - organic knurled handles. Primitives would
  look worse than the donor.
- `PR-12-Side-Rear-R` (6,631), `PR-11-Side-Rear-L`, `PR-15-Top-Deck`, `PR-16-Top-Cover`, `PR-17-Front-Sight-Boss` - flat panels carrying the M2's
  rivet and rib detail. The rivets are a trivial pattern; the panel outlines and raised detail
  are freeform and would take days to approximate badly.

Reauthoring those means re-drawing HappyBattleSheep's artwork, which is the thing worth keeping.

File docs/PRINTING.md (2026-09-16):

# Printing the skins

Everything in the table below that is a **coordinate, footprint or orientation is measured
from the model** by `tools/bedcheck.js` and `tools/stlcheck.js`. Everything that is a
temperature or a speed is a **starting point** from one reported failure on one machine —
tune it.

Reference machine: **Creality K1 Max**, 300 × 300 × 300, **smooth PEI**, **0.6 nozzle at
0.3 mm layer height**, PLA.

> **Check which plate is actually on the machine.** The slicer profile says
> `textured_plate_temp` and bed type 3, and this build ran on smooth PEI regardless. Two
> agents reasoned about the wrong surface for an entire session off the profile name. It
> only failed to cause harm because every plate-type temperature key had been set to the
> same value.

---

## Orientation — this is the part that matters

Each part goes on the face with the **largest measured flat contact area**. For the skins
that is the tube-mating (inner) face, which is what `tools/reauthor/flatten_mating.py`
made flat and what lets you iron the outside.

**Measure the area, not a percentage.** `bedcheck` reports both, and ranking by
"% of bed-facing area" picks the **wrong face on 6 of these 18 parts** — the denominator
changes with orientation, so a face with 73.7% of a tiny bed-facing total beats one with
42.7% of a large one while having a tenth the actual contact. Rank by cm².

| part | bed face | contact | height |
|---|---|---:|---:|
| `PR-11-Side-Rear-L` | Y min | 333.10 cm² | 24 mm |
| `PR-12-Side-Rear-R` | Y max | 337.45 cm² | 37 mm |
| `PR-13-Side-Front-L` | Y min | 218.80 cm² | 24 mm |
| `PR-14-Side-Front-R` | Y max | 218.80 cm² | 24 mm |
| `PR-15-Top-Deck` | Z min | 106.34 cm² | 66 mm |
| `PR-16-Top-Cover` | Z min, **rotated 45° about Z** | 118.77 cm² | 30 mm |
| `PR-17-Front-Sight-Boss` | X max | 32.41 cm² | 38 mm |
| `PR-18-Bottom-Rear` | Z max | 133.29 cm² | 26 mm |
| `PR-19-Bottom-Front-L` / `-R` | Y min | 11.06 cm² | 3 mm |
| `PR-21-Barrel-Jacket` | X max | 22.59 cm² | 262 mm |
| `PR-31-Spade-Grips` | Z min | 9.00 cm² | 126 mm |
| `PR-41-CH-Handle` | Y max | 14.96 cm² | 133 mm |
| `PR-42-CH-Carrier` | Y min | 15.96 cm² | 16 mm |
| `PR-43-CH-Shoe` | Y min | 4.95 cm² | 8 mm |
| `PR-51-Trigger-Butterfly` | Z min | 6.72 cm² | 63 mm |
| `PR-52-Trigger-Switch-Carrier` | Z max | 12.24 cm² | 43 mm |
| `PR-61-Engine-Cradle` | Z min | 57.90 cm² | 43 mm |

**"Thinnest axis down" is a bounding-box heuristic and it is blind to what is actually
touching the plate.** It fails on round shells and tall organic shapes. Placed that way,
`PR-21-Barrel-Jacket` and `PR-41-CH-Handle` both get **0.00 cm²** of flat contact — a
cylinder lying down touches on a *line* — and `PR-51` gets 0.08 cm². All three would have
gone to the plate resting on nothing.

Check any part with `node tools/bedcheck.js <stl> <axis> <min|max>`.

---

## The long panels warp, and a brim will not save them

`PR-11` and `PR-12` are 295.6 mm long. PLA contracts about 0.4% as it cools, so each is
trying to shrink **~1.2 mm along its length, 0.6 mm at each end**, and that force peels the
end corners off the plate.

A brim is not available in the direction that matters. The design sits at the bed limit on
purpose — `BUILD-NOTES.md` puts the seam at X −265 because *"max forward is X −260.6 before
Side_1 exceeds the 300 mm bed"* — which leaves **about 1.1 mm at each end.**

**Print `stl/print-aids/PR-11-Side-Rear-L-ears.stl` and `-PR-12-Side-Rear-R-ears.stl`
instead of the plain versions.** Four ⌀20 × 0.6 mm pads at the corners, growing sideways
into the 165 mm of spare bed rather than lengthwise into the 1.1 mm that is not there.
Snap them off afterwards.

The pads are **0.6 mm = exactly two layers at 0.3 mm**. A pad thinner than one layer gets
dropped or rounded up at slice time and looks like the fix failing. **Change layer height →
change `PAD_T` in `tools/reauthor/print_aids.py` and regenerate.**

`PR-13` / `PR-14` have 14 mm to spare. Just use a normal brim on those.

---

## Settings

Ordered by how much they mattered on the reported failure.

| | setting | why |
|---|---|---|
| 1 | **Auxiliary / side fan OFF for the first ~10 layers** | The K1 Max stock PLA profile runs it hard and it blows straight across a 296 mm first layer. Biggest single lever. |
| 2 | **Part cooling 0% for layers 1–3**, then ramp | Same reason, less severe. |
| 3 | **Keep the enclosure shut** | Chamber heat works *for* you against warping. Stock PLA profiles often want the door open — wrong for parts this long. |
| 4 | **First layer 30–50 mm/s, reduced acceleration** | The K1 Max does 20,000 mm/s². That is real shear on a marginally-attached 296 mm part. |
| 5 | **Bed 60 °C, soak 5+ min** | The edges lag the centre sensor, and these parts end exactly at the edge. |
| 6 | **Z-offset one notch lower** | At 0.6/0.3 an under-squished first layer still looks fine. |

**Plate prep depends on which plate you have, and the two want opposite things.**

*Smooth PEI* — grips clean PLA **harder** than textured, not less. A lift here points at
contamination or nozzle height long before it points at temperature. Wash with **dish soap
and warm water** to lift skin oils, then a **final IPA wipe**; on this surface the IPA step
matters, because smooth PEI has no mechanical key and is working on surface chemistry
alone. Glue stick here is conventionally a **release** agent — used to stop PLA bonding so
hard it tears PEI off the sheet — not an adhesion aid.

*Textured PEI* — keys mechanically, tolerates worse prep, and glue stick genuinely does
reduce grip for PLA.

**On smooth PEI the end of the print is the dangerous part.** Over-adhesion scales with
contact area, and two parts in this set dwarf the rest:

| `PR-12-Side-Rear-R` | 337.4 cm² |
|---|---:|
| `PR-11-Side-Rear-L` | 333.1 cm² |
| next largest (`PR-13`/`PR-14`) | 218.8 cm² |
| `PR-21-Barrel-Jacket` | 22.6 cm² |

**Let the plate reach room temperature before flexing either of those two off.** Warm
smooth PEI plus 333 cm² of PLA can take the PEI sheet with it. That risk rises with bed
temperature — 65 °C is the top of the sensible range for PLA on smooth PEI.

**The usable envelope is smaller than 300 mm for real geometry.** Creality Print 7.2
refuses to place a 297.6 mm part at all — *"Nothing to be sliced … no object is fully
inside the print volume"* — while a featureless box of the same size slices fine.
Bracketed on the real mesh: **297.6 rejected, 296.1 rejected, 294.6 slices**, and
`PR-18` at 295.6 slices. Treat ~296 mm as the practical ceiling, not 300.

This is why the corner pads add **zero** length: they sit tangent to the part's ends, so
the eared files are 295.6 mm, exactly the same as the plain ones. The bond they add comes
from the half-disc overhanging *sideways*, which costs nothing in the constrained axis.

**A defect smaller than the layer height is invisible to the slicer.** PR-16 had an
0.15 mm standoff and sliced to **identical G-code before and after the fix — 171.99 g both
times.** At 0.3 mm layers the first layer is sampled mid-layer at z = 0.15, where both the
pads and the "floating" face are present. The fix added 1.39 cm³ and the floating band is
1.335 cm³ — i.e. the fix added exactly the material the slicer was already ignoring. The
geometry is correct now and it matters at finer layer heights, but **it changed nothing
about this print.** Check a defect against layer height before calling it a print problem.

**`brim_type = outer_brim` is silently ignored by Creality Print 7.2** and falls back to
`auto_brim`, which often decides a large flat part needs no brim at all. Accepted values in
that build are `auto_brim`, `outer_only`, `no_brim`.

---

## Debugging a failure

Match the symptom before changing anything:

| what you see | what it is | what to change |
|---|---|---|
| Corners lift at the **ends of the long axis**, middle stays down | contraction / warp | ears, fan, chamber heat |
| Whole part breaks free early, first layer **shiny, not squished** | Z-offset or bed temp | squish and temperature |
| Fails **hours in**, partway up | draft or cooling | close the enclosure, drop fan |
| **Nothing sticks anywhere** from the start | surface contamination | wash the plate — *this* is when glue is the answer |

**Validate settings on `PR-13` or `PR-14` first.** They are 271 mm with brim room, so if
those still lift, the problem is the plate or the Z-offset and the ears will not save the
long ones either. Six hours is a long time to find that out on `PR-12`.

---

## Material

**3,542 cm³ across 18 parts — about 4.4 kg of PLA at 100% infill**, and considerably less
in practice. These are non-structural skins; the steel carries everything. There is no
reason to print them solid.

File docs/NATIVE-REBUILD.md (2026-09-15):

# Native rebuild — tracker

> **Names in this document are the donor's**, because it is about converting donor
> geometry. The parts have since been renamed to a single catalogue — see
> **[PARTS.md](PARTS.md)**. Watch out: the donor's `Side_L*` are physically on the
> **right** of the gun, and the catalogue names follow the physical side.

Replacing the donor-derived **faceted** bodies with **native analytic** geometry authored from
primitives. Faceted bodies are STL conversions: thousands of triangular planar faces, no real
cylinders, slow booleans, bloated STEP, nothing editable.

Everything designed from scratch for this project is **already native** — the core tube is 135
faces with 73 real cylinders, the weldments are 4–32 faces each. Only the donor-derived cosmetic
parts are faceted.

> **Fusion cannot do this automatically.** `PrismaticMeshConvertMethodType` returns output
> identical to `Faceted` in every configuration tested, including with Accurate face groups
> generated first. It appears to need the Product Design Extension. See BUILD-NOTES.

---

## Status

| # | Part | Faces | Status | Volume | Notes |
|---|---|---:|---|---:|---|
| 1 | `Grip_Assembly` | 17,621 | ✅ **1,549** | −2.0% | Handgrips and buffer tube are **exact revolves**; frame is a stack of plan sections. |
| 2 | `Barrel_Jacket` | 17,422 | ✅ **60** | −27% | Revolution + regular hole pattern. 290× reduction. |
| 3 | `CH_Handle` | 10,134 | ✅ **73** | +0.6% | Knob is an **exact revolve** — 3 faces. Plate, arm, 4 × ⌀8 nut pockets. |
| 4 | `Side_L1` | 6,631 | ✅ **262** | −0.9% | CH slot, 16 domed rivets, ⌀19 boss, five stepped tiers. |
| 5 | `Side_R1` | 5,230 | ✅ **162** | −2.7% | Domed rivets, the ⌀6 pin drift hole, the top bracket. |
| 6 | `Hatch` | 2,772 | ✅ **138** | −1.2% | Prismatic runs + straight ramps. **Fixed a real interference** — see below. |
| 7 | `Side_R2` | 2,289 | ✅ **75** | −1.6% | Spherical rivet dimples, conical boss where the left has a rear panel. |
| 8 | `Side_L2` | 1,913 | ✅ **84** | −1.7% | Layered plate, 9 dimples at 18.31 pitch, 6 M3 bosses. |
| 9 | `FrontBoss` | 1,705 | ✅ **250** | −1.3% | Front sight hood and post, 12 rectangular standoff ribs. |
| 10 | `Top1` | 1,169 | ✅ **61** | −0.9% | Planes + cylinders only. Six ⌀8 bridging bosses under the deck. |
| 11 | `Trigger` | 611 | ⚠ **partial** | — | The lever *is already native*; the butterfly paddle defeated three attempts. |

**Already native, nothing to do:** core tube, all 11 weldments, `Cradle_F2_HopUp`, `CH_Carrier`,
`CH_Shoe`, `Trigger_Switch_Carrier`, `Bot1`, `Bot2`.

### Where it landed

**66,886 faces of donor mesh replaced by 2,714 native ones — a 25× reduction**, across every part
except the trigger's butterfly paddle. Each is a single watertight shell, and **every bounding box
now matches its donor to better than 0.25 mm** in all three axes.

Volumes land within 2.7% except the jacket, which is a deliberate simplification. Those ten parts
are **2,957 cm³ native against 3,230 cm³ faceted** — recomputed from the meshes, donor totals taken
from `stl/donor/`.

**That is the ten reauthored parts, not the printed set.** All 18 printed parts together are
**3,498 cm³** — see `docs/PARTS.md`. The other eight were already native and never went through this
process, so they appear in neither figure above. An earlier version of this line said "the whole
printed set", which made a number covering ten parts look like it covered eighteen.

Only 611 faces remain faceted, and only the paddle within that.

### The two I wrongly wrote off

The first version of this table marked `CH_Handle` and `Grip_Assembly` "not worth it — organic,
knurled, the most sculptural parts on the gun." **Both are wrong.** Measured with the same
first-hit-radius method used on the jacket:

| | axis | agreement across rays |
|---|---|---|
| CH knob | Y at (X −286.80, Z 48.875) | **0.008 mm** over 64 rays |
| Handgrips | Z at (X −613.81, Y ±62.23) | **0.006 mm** over 48 rays |

They are not knurled at all. They are **turned** — bodies of revolution to eight microns, the
easiest case there is. Each is now a single revolve of **3 faces**. What made them look organic in
the browser was 10,000 triangles, which is exactly the trap this document already warned about for
the side panels, and I walked into it twice more.

---

## The hatch could not close — found by rebuilding it

The steel hinge tabs are 1/8 in plate at Y ±19.18…22.35 with an arc top of r8 about
the hinge pin at (X −9, Z 62.5), rising to Z 70.5. **The donor cover is solid straight
through that corridor.** Fitted as drawn it fouls the tabs by roughly 12 mm and cannot
shut. The donor's clearance slots only begin at X −18; the tabs start at X −22 and are
already 66 mm tall by X −18.

This never showed up in the earlier clash audit because **the boolean against the
faceted donor reported "clear"** — a false negative. Probing the same corridor with
small boxes and reading the volumes showed it 100% solid. Faceted-body booleans cannot
be trusted; see `tools/reauthor/README.md`.

The native cover cuts the clearance as an **r8.5 arc about the hinge pin**, not a plain
slot — the tab has to clear at every angle of the swing, not just when shut. Verified:
0.00000 cm³ overlap with both tabs.

> The faceted `Hatch` still carries this fault. Print `Hatch_native.stl`.

---

## Trigger — the lever is native, the paddle is not

> This is now the **only** faceted part left, and only its paddle.

The functional half was already native and stays exact: riser X −580…−568 (Y ±7,
Z −6…32), arm X −568…−526 (Y ±6, Z −6…8), ⌀4.20 pivot bore on the Y axis at X −552,
⌀6 spring peg, ⌀3 front anchor.

The butterfly paddle resisted three separate reconstructions:

| attempt | result |
|---|---|
| Loft, arc-length resampling | Sections twisted — no point correspondence between them |
| Loft, angular resampling about the centroid | Filled the V notch; the sections are crescents, not star-shaped |
| Two-view silhouette intersection | Over-fills the wings — 840 mm² against an actual 396 mm² |

It is a compound-curved paddle with serrated thumb pads. Note that the same verdict was
originally given to `CH_Handle` and `Grip_Assembly` and was **wrong for both** — they turned
out to be exact revolves. The difference is that those two are round about an axis and this
is not: the paddle's sections are crescents that change character along the sweep. Left
faceted at 611 faces, which is cheap.

---

## What I got wrong about the panels

An earlier version of this document said the side panels were marginal — that their rivet rows and
raised ribs were freeform artwork that boxes and cylinders would only make worse, and that each
would take days.

That was wrong, and measuring them properly is what showed it. The rivets are a **linear pattern**:
nine at 18.31 mm on `Side_L2`, and two rows of eight at 36.85 and 28.30 on the rear panels. The
raised "ribs" are **flat tiers at constant depth**. The panel outlines are straight lines with
chamfered corners and castellated interlocking tabs. The only genuinely freeform things on the gun
are the two grips, the charging-handle knob, and the trigger paddle.

The test still holds — **is it a revolution, an extrusion, or a plate with prismatic features?** —
but you have to run the scan before answering it. Eyeballing a dense mesh makes everything look
organic, because tessellation looks organic.

The other half of the correction came from Eric: *map it to normal straight lines, this thing was
designed in the early 1900s, it's not complicated.* That is exactly right, and it is why `snap.js`
exists. The wobble in the donor mesh is scan noise on top of what was originally flat plate, and
straightening it produces geometry that is both smaller and closer to the real gun.

---

## Method that worked

Recorded because two earlier attempts produced visibly wrong geometry.

### 1. Get the profile
Bin STL vertices by X, report the radius percentiles per bin. Gives the outer profile and the bore
directly. Watch for **empty bins** — a long smooth prismatic run carries vertices only at its ends,
which reads as a gap but is not one.

### 2. Get the hole pattern by RAY-CASTING, not occupancy
Two wrong answers came from vertex occupancy before this worked.

- **Vertex occupancy fails.** A smooth cylindrical band has vertices only at its edges, so empty
  bins read as holes.
- **Counting ray hits fails.** Every ray crosses the far wall, so everything reads as solid.
- **First-hit radius works.** Cast inward from outside the part on an (x, θ) grid and record the
  radius of the nearest intersection. Near the outer radius means wall; anything deeper is a hole.

For the jacket this gave 4 holes per row at 90°, **alternate rows offset 45°**, pitch 25.5, ⌀26.
An earlier occupancy read said 8 aligned rows of ⌀20 and looked obviously wrong beside the donor.

### 2b. For plate and box parts, scan for prismatic runs first
`tools/reauthor/scanx.js` plots cross-sectional area against station. Long stretches
of identical area are constant-section runs — extrude those. Steps between them are
where the profile changes. The hatch turned out to be five constant runs and two
straight ramps; Top1 was six runs and six blind holes.

**Straighten before authoring.** `snap.js` clusters measured coordinates onto shared
values. The M2 was designed in 1918 out of flat plate — the wobble in the mesh is scan
noise, not intent, and straight lines both read better and model smaller. Keep the
round-number tolerance under 0.06 mm so real dimensions (12.70 = ½ in) survive.

### 3. Author from primitives
Stack `createCylinderOrCone` segments for the profile, boolean the bores, pattern the holes.

**`tbm.booleanOperation` returns a bool, not a body.** `body = tbm.booleanOperation(...) or body`
assigns `True` and the next call dies. This has now cost time three times in this project.

### 4. Verify before trusting it
Clash the new body against every steel part and neighbouring skin, check `isSolid`, check shell
count, and check any functional channel still runs clear — for the jacket, that the hex key still
reaches the set screws.

---

## Jacket — what was built

| | faceted | native |
|---|---|---|
| Faces | 17,422 | **60** (21 planar, 36 cylindrical, 3 conical) |
| STEP | ~1 MB | 345 KB |
| Volume | 879.3 cm³ | 638.0 cm³ |

Profile measured off the donor: rear flange r50.80 to X 38, taper to r41.35 by X 41, r41.35 to
X 82, taper to r39.60 by X 90, main tube r39.60 to X 272, muzzle flange r41.40 X 272…284.

**The close bore runs the full length of the socket** — ⌀38.90 from X 24.8 to 118, giving **89 mm
of grip** on the ⌀38.10 socket. The first attempt opened the bore to ⌀58.26 at X 46, which left
the jacket located over only 21 mm with a 10 mm radial gap for the next 67 mm — it would have
wobbled. Perforations start at X 130 so the grip section stays solid.

**The rear flange is flat at Y ±29.8**, full r50.80 only at top and bottom. Measured off the donor:
full radius appears only in the 55–125° and 235–305° bands. This is where the jacket meets the
receiver, and the receiver front is Y ±30 — so the flats sit flush with the sides.

### Still missing on the native jacket
- The donor's rear bracket has **rectangular cutouts** in the flange; the native one is plain.
- Volume is 638 vs 879 cm³ — the native profile is simplified and the perforation layout differs.

Kept **alongside** the faceted part (`Barrel_Jacket_native.stl` / `.stp`) rather than replacing it,
until those are resolved or judged unnecessary.

---

## Hatch and Top1 — what was built

| | Hatch faceted | Hatch native | Top1 faceted | Top1 native |
|---|---|---|---|---|
| Faces | 2,772 | **122** | 1,169 | **49** |
| Volume | 516.81 cm³ | 509.83 | 472.87 cm³ | 468.63 |
| Difference | — | −1.4% | — | −0.9% |
| Symmetric difference vs donor | — | 2.2% | — | 1.3% |

**Hatch**: main run X −333…−119, widening to the front block over −119…−108, the
underside opening −101…−40, nose taper −32…−16, front sight aperture to −4.4. Three
hinge knuckles (r3.47 about Y 24.5, Z 67.03) and the rear sight base as a truncated
pyramid — which is what the donor actually is, a trapezoid in both elevations, not a
dome.

**Top1**: constant width Y ±25.8 throughout. Rear underside notches, a crowned main
run, the tall rear-sight block X −495…−432.5 with straight ramps at both ends, and six
⌀3.40 blind holes (Z 30.5…51.0) at X −526.7 / −413.5 / −356.9, Y ±18.

Top1 is entirely planes and cylinders — no NURBS at all.

### Still missing
- Hatch: the small top-centre slot near the rear (X ≈ −325) is not reproduced.
- Both: the donor's corner radii are replaced by straight chamfers, which is where
  most of the ~1% volume difference comes from. This is deliberate — the M2 is a
  plate-and-rivet design, and straight chamfers read closer to the real gun than
  the mesh's rounded-over edges do.

---

## The panels — what was built

All four side panels are plates normal to Y, built as stacked constant-depth tiers with the
holes cut as real cylinders rather than snapped polygons.

### Side_L2 / Side_R2 (forward)

| tier | \|Y\| | content |
|---|---|---|
| plate | 25.85 … 30.00 | outline, CH-side castellations, 9 rivet dimples |
| raised panel | 30.00 … 38.00 | front panel; the left also has a rear panel to 40.50 |
| outer tier | 38.00 … 44.00 | two regions, chamfered to 49.09 |
| bosses | 25.40 … 25.85 | 6 × ⌀8 bridging to the tube face |

Rivets: 9 × ⌀1.50 at Z −39.80, pitch **18.306**, from X −169.55. Fasteners: 6 × ⌀3.40 at
X −242.40 / −122.90 / −63.10, Z +8.00 / −24.00, plus one ⌀7.52 at X −115.98, Z 0.

**The two are not mirrors.** The left carries a raised rear panel (1,180 mm², 12.3 cm³); the right
has a conical boss at X −222.7, Z 31.0 instead. That is the whole 12 cm³ difference between them.

### Side_L1 / Side_R1 (rear)

Five tiers from the plate at \|Y\| 25.85–30 out to 46.5 (left) or 46.2 (right). The charging-handle
slot is **198.3 × 10.18 mm** at Z −13.04…−2.86, and it runs through *both* panels — the carrier
sandwiches the tube, so both skins need the clearance.

Two rivet rows, generated arithmetically rather than read back off the mesh (the read missed a head
and gave different diameters row to row):

- Z −55.50, from X −541.84, pitch 36.852, 8 heads
- Z +56.30, from X −541.84, pitch 28.298, 8 heads

Left-only: the ⌀19 boss at X −293.8, Z −29.6 standing 15 mm proud. Right-only: the ⌀6 pin drift
hole at X −552, Z 1, and the raised bracket on the top edge — which is **three ⌀12 pads on a flat
bar**, not the wavy outline the mesh traces.

The donor drafts continuously through these tiers; the native version steps. That is the deliberate
trade and it is where the 4–6% symmetric difference comes from — the M2's side plate is stamped
sheet with stepped panels, and straight steps read closer to the real gun than a smooth taper does.

### FrontBoss

Six prismatic runs along X, from the twelve plain rectangular standoff ribs on the rear face
(X −13.35…−3.0) out to the sight hood and post (X 8…19). 309 faces.

**Transverse features cannot survive a prismatic reconstruction.** Anything running side to side
along Y gets sliced by each X run at a different chord and extruded flat, so a round feature comes
out as a staircase. Three separate things on this part were wrong because of it:

- **The ⌀6.65 hinge pin bore was a square gap.** The ears are built as rib slabs that stop at
  Z 59.4 and resume at Z 65.7, so the "bore" was simply the rectangular space between two slabs —
  a jagged square where a diameter should be. Fixed by filling that gap across the bore's footprint
  in each of the four ears (Y −30…−22.35, −19.18…−18, 18…19.18, 22.35…30) and then drilling it:
  **369.0 mm² of bore wall against 368.9 mm² expected** for a ⌀6.65 hole through 17.66 mm of ear.
- **Three ⌀6.6 domed bosses were stepped pyramids.** Round-head rivets, same as the side panels,
  fitted at R 3.38 about |Y| 28.95. With no dome covering the view, the thin internal slots behind
  them showed through and read as striped squares.
- **A profile was sampled straight through a boss.** `FB_E` was taken at X 13.5, inside a boss
  footprint, so straightening smeared the boss's |Y| 32.1 across the whole outline and the flange
  ran out to X 19 where the donor stops at 7.8 — 11 mm of phantom material. **Sample prismatic
  runs at a station clear of every local feature**, or the feature contaminates the whole run.

**The front mounting hole is BLIND, one per side.** Measured on the donor: ⌀5.96 at the |Y| 30.0
face, closing to ⌀1.4 by |Y| 28.0 and bottoming at 27.8 — a pilot for a self-tapping screw.
Drilling it straight through instead cut a slot clean across the part and out through the window
behind it. **Check how deep a hole actually goes before assuming it is a through hole.**

Two passes were needed on the ear as well. Filling the gap only ±3.6 mm about the bore left a
2.4 mm slot running out of it at X −5.40…−3.00, because the rib run is X −13.35…−3.0 and the donor
ear is solid over all of it bar the round hole. Fill the whole run, then drill.

### Census the holes, do not spot-check them

Three rounds of this part were "fixed" by checking the one feature that had been complained about.
What finally worked was `tools/reauthor/holediff.js` — walk both solids in parallel sections on an
axis, match every hole to its nearest counterpart, and report what is MISSING, EXTRA or the wrong
SIZE. Run it on all three axes. It found in one pass what three rounds of eyeballing had missed:

- **Two junk slots, 0.70 mm and 0.65 mm tall, plus two of 0.00 mm.** Mesh tessellation noise that
  the profile extractor had faithfully copied as real features — and they were what rendered as
  stripes. **Drop any hole under a millimetre in either direction.**
- **The window opened a millimetre early**, at X 8.00 instead of the donor's 8.75 — a run boundary
  in the wrong place.
- **The opening between the inner ears tapers shut** over X −3.4…−2.0 rather than stopping dead at
  the rib run, so it was being closed off early.

Sample the sections **off** the run boundaries, or every boundary reports a false difference.

Verified section by section: the ear hole is `X −12.32…−5.67, Z 59.17…65.83` on both sides,
matching to the hundredth, and the YZ section at the mounting hole matches too.

### Fill before you trim

The scallop in the bottom edge is a **circle**, R 8.00 about (X 1.00, Z −33.40) — a least-squares
fit to the donor outline lands on it at 0.00 mm — cut through the two walls at |Y| 25.8…30.0. The
prismatic runs approximated it with a four-step staircase, and that staircase is the single most
visible defect this part had.

Trimming the staircase back to the arc **splits the part into seven shells**: in this
reconstruction the staircase corners are load-bearing. The fix is to go the other way — **fill the
band beside it first, then cut the real cylinder.** 250 faces, one shell, and the boundary now sits
at radius 8.00 at every point.

### A run boundary in the wrong place is an 18 mm slab

Between X 7.9 and X 8.75 two separate things happen: the wide flange **ends** (|Y| drops 44.78 →
30.00) and the window **opens**. Collapsing both into one run left an 18 mm slab of phantom flange
standing out each side — and "fixing" the window boundary alone made it 0.85 mm worse. They need
their own runs. The flange's taper is an arc too, R 4.95 about (X 2.843, |Y| 44.134); trimming it
to the chord instead took 1.2 mm too much out of the middle.

**Probe the solid, do not read outlines.** Deciding whether a feature was a boss or a void from the
boundary path got it backwards twice. Point-sample material on a grid and compare to the donor;
129 stations across this scallop now agree exactly.

---

## Two more interferences, both mine

Found by clashing the finished native set against itself. Neither existed in the donor:

- **Hatch nose into the FrontBoss ribs, 0.375 cm³.** I held the nose at full width (Y ±30) to
  X −12; the standoff ribs start at X −13.35. The donor narrows between −14 and −12. Fixed by
  narrowing at −13.50.
- **Side_R1 bracket into the hatch skirt, 0.095 cm³.** The tier under that bracket stops at
  X −334.4, which is exactly where the top cover starts. Past that the bracket overhangs the
  cover, so its underside has to begin outboard of it — the donor does the same. Fixed by trimming
  the overhang back to \|Y\| 34.95.

Both are the kind of thing that only shows up once the geometry is clean enough to boolean
honestly. Against the faceted donors, these checks returned "clear".

---

## Rivets are round-head rivets

Every raised disc on the gun is a **spherical dome**, not a flat-topped cylinder. Fitted against
r² = R² − (Y − Yc)² off the donor mesh:

| feature | centre \|Y\| | R | max deviation |
|---|---:|---:|---:|
| `Side_L1` rivet heads ×16 | 33.546 | 4.219 | 0.23 mm |
| `Side_R1` rivet heads ×16 | 33.525 | 4.223 | 0.25 mm |
| `Side_L1` upper studs ×4 | 28.953 | 3.380 | 0.10 mm |
| `Side_L1` mid studs ×3 | 35.554 | 4.394 | 0.11 mm |
| `Side_R1` tier studs ×2 / ×4 | 28.346 / 28.966 | 5.269 / 3.360 | 0.15 mm |
| `Side_R1` bracket rivet | 44.529 | 5.138 | 0.29 mm |

The two rear panels carry the *same* rivet, agreeing to 0.005 mm. The first pass built the left
ones as flat cylinders and the right ones as cones, which is what made the two sides look different.

**The inset holes are spherical too.** The forward panels' rivet detail is a ⌀5.9 spherical dimple
2.1 mm deep (R 3.125 about \|Y\| 31.035); the first pass measured the diameter *deep inside* the
dimple and cut ⌀1.50 pin holes — wrong in both size and shape. The small recesses on the rear
panels are likewise spherical (R 2.95 on the left about \|Y\| 37.28, R 3.00 on the right about
34.01), not flat-bottomed bores. The ⌀9.98 recesses genuinely are flat-bottomed cylinders.

A dome is a whole sphere, so its far hemisphere sits *inside* the panel and can break out through
the inboard face — `Side_R1` ended up 2.3 mm inside the tube before the parts were clipped back
to the tube face at \|Y\| 25.40.

---

## Four truncations, found by auditing bounding boxes

After fixing one shortfall by hand it was obvious to check them all. Comparing each native part's
bounding box against its donor found four, every one a case of stopping at a round number instead
of where the geometry ends:

| part | axis | donor | first pass | short |
|---|---|---:|---:|---:|
| `Side_R1` | Y max | 49.70 | 46.20 | **3.50 mm** |
| `Hatch` | X min | −334.34 | −333.00 | **1.34 mm** |
| `Side_L1` | Y min | −62.30 | −61.50 | **0.80 mm** |
| `Top1` | Z min | 30.15 | 30.50 | **0.35 mm** |

- `Side_R1` — a domed rivet on the bracket's centre pad, lopped off by a tier ending at 46.2.
- `Hatch` — a rear end chamfer over X −334.3…−332, asymmetric: it tapers on the −Y side and the
  top while Y max stays 34.90.
- `Side_L1` — the ⌀18.98 boss is flat-ended at \|Y\| 62.25, not 61.50.
- `Top1` — the one that mattered: **six ⌀8 bridging bosses under the deck** at the M3 positions,
  standing 0.35 mm proud. The same bosses the side panels carry, the ones that land the deck on the
  tube. They had been omitted entirely and the holes drilled straight through a flat face.

**Make the bounding-box audit routine.** It is cheap, it needs no Fusion, and it catches exactly
the class of error that volume comparison hides — 0.35 mm of missing boss costs almost no volume.

---

## Grips and charging handle — what was built

**CH_Handle**, 73 faces. One revolve for the knob (Y −171.45…−58, r 9.97 at the tip swelling to
15.83 and back to 11.67), the mounting plate over Y −58…−48, and the flat arm X −386…−280 over
Y −48…−38 carrying **four ⌀8 blind nut pockets** at X −370 / −340 / −310 / −290, Z −5, entered
from the outboard face. Plus the ⌀19 boss at (X −293.6, Z −8.02).

**Grip_Assembly**, 1,463 faces. Two revolved handgrips — barrel-shaped, r 12.81 at the base
swelling to 15.87 and shouldered into a domed top at Z 72.1 — on a frame built from **33 horizontal
plan sections**.

An earlier attempt extruded the fore-aft *side* profile across the full width and trimmed it
against one plan section per half. That was 10% light and it also filled in the slot the trigger
passes through. The spine's plan changes shape the whole way up; it is not a slab with a constant
outline. Sampling the plan every 1 mm, cutting bands at the real transitions and merging identical
ones gives 33 bands and lands within 2%.

The mounting tongue reaches into the receiver, so the grip is relieved against the tube, the
backplate and its bosses, and against the **trigger swept through its 6° of travel** — otherwise it
fouls partway through the pull rather than at rest.

**Lofting between the plan sections was tried and rejected.** The prisms leave a visible terrace
at every band boundary, so the obvious fix is to sweep between adjacent profiles instead. Measured,
it was worse on every count: **−6.1% on volume against −2.0%** (a loft cuts the corner where a
mid-band prism averages it), **two shells instead of one**, two new clashes into `PR-15-Top-Deck`
and `PR-18-Bottom-Rear`, and 415 NURBS faces where the prisms give planes. The stepping is the
honest cost of the more accurate construction, and it stays.

**The buffer tube is a plain cylinder** — ⌀34.78, measured to 0.015 mm across 64 rays, with a
chamfer back to ⌀27.48 at the end face and a 3.3 mm wedge slot across it. It was first made by
*intersecting* the plan-section stack with a cylinder, which left the stack's stepped
approximation showing through instead of a turned surface. Cut the stack off behind the frame and
add the real cylinder. Order matters: the handgrips reach back to X −629.7, so the blanket cut
behind X −628 is only safe before they are unioned in.

---

## Two more lessons

**Do not approximate a revolve with a stack of cone segments.** Forty-four segments through the
measured radius profile is geometrically fine and renders as visible rings — it looks *knurled*,
which is the one thing these turned parts are not. A single `revolveFeature` through a fitted
spline is 3 faces and actually smooth.

**When merging bands, put hole topology in the merge signature.** Merging two bands keeps the
first one's profile. If a slot appears in only some bands of a group, merging silently fills it
back in — which is how the trigger's clearance slot disappeared.

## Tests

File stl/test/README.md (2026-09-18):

# Bed levelling test

`bed-level-squares.stl` — five concentric single-layer frames. Nothing else. Regenerate with `node tools/bedlevel.js`.

**`tools/bedlevel.js` is the source of truth for the STL.** There is also a copy in the
Fusion model (`tools/reauthor/build_bedlevel.py` → `00_Ref_Test_Artifacts` /
`RF-90-Bed-Level-Squares`) so the thing can be seen and measured alongside the gun. The
constants are duplicated in both files and nothing keeps them in step — change one,
change the other.

Two things about where the Fusion copy lives, both deliberate: it sits in a `00_Ref_*`
component, which every clash and audit script in this repo skips, and it is parked at
**Z −400**, well clear of a gun that bottoms out at Z −92. Without both, a 290 mm square
lying at the origin would intersect the tube and most of the skins, and every
interference check in the project would come back garbage.

Built for the **K1 Max at 0.6 nozzle / 0.3 mm layer**. Three numbers are tied to that:

| | | why |
|---|---|---|
| height | **0.30 mm** | exactly one layer. A test artifact thinner than the layer height gets rounded up or dropped at slice time — the trap `PR-16`'s 0.15 mm standoff fell into |
| width | **1.20 mm** | exactly two 0.6 mm beads. Slices predictably anywhere, and under-squish shows as a visible gap down the middle |
| outer frame | **290 mm** | Creality Print refuses real geometry at 297.6 mm on this bed — bracketed at 296.1 rejected / 294.6 accepted. 290 leaves margin without giving up the edges, which are the part you care about |

**Change the layer height → change `H` in `tools/bedlevel.js` and regenerate.**

## Printing it

- **No brim, no raft, no supports.** 0% infill is irrelevant, it is one layer.
- Same first-layer settings you intend to use for real parts, or the test tells you
  nothing about them.
- 5 separate shells is expected, one per frame.

## Reading it

Look at each ring, and compare sides *within* a ring rather than between rings:

| what you see | what it means |
|---|---|
| glassy, wide, beads merged flat | over-squished — nozzle too low there |
| rounded, narrow, a gap down the middle | under-squished — nozzle too high there |
| one side of a ring differs from the opposite side | **tilt**, not nozzle height |
| outer ring poor, inner rings fine | the bed is domed or the mesh does not reach the edges |

The concentric layout is what separates those last two from a simple Z-offset error: a
Z-offset problem looks the same everywhere, tilt does not.

## Context for this machine

The stored mesh on this K1 Max spans **0.665 mm** — 2.2 layer heights at 0.3 mm — with
the left end at +0.44 to +0.21 and the right at +0.10 to +0.12. The probe grid also stops
at x 295 while parts run to x 297.8, so the outer few mm are extrapolated. Expect the
right side to read under-squished relative to the left until that is fixed.

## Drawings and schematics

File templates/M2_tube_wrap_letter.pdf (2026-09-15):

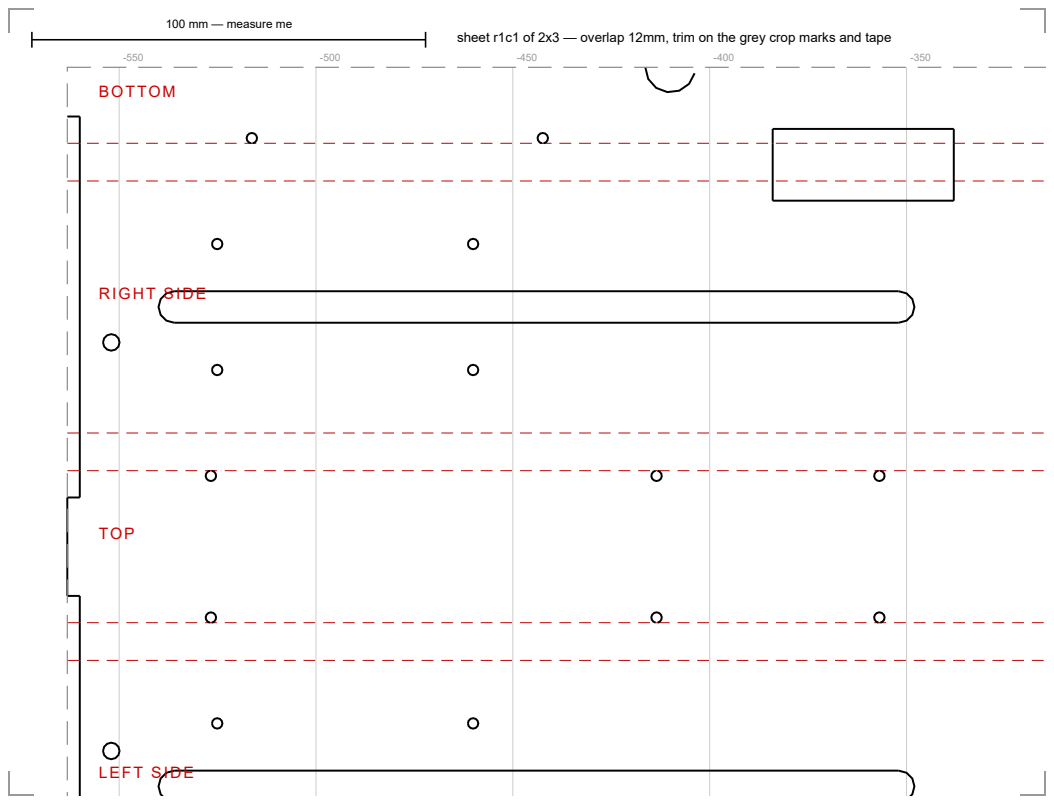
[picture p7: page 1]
BOTTOM; RIGHT SIDE; TOP; LEFT SIDE

100 mm — measure me

sheet r1c1 of 2x3 — overlap 12mm, trim on the grey crop marks and tape

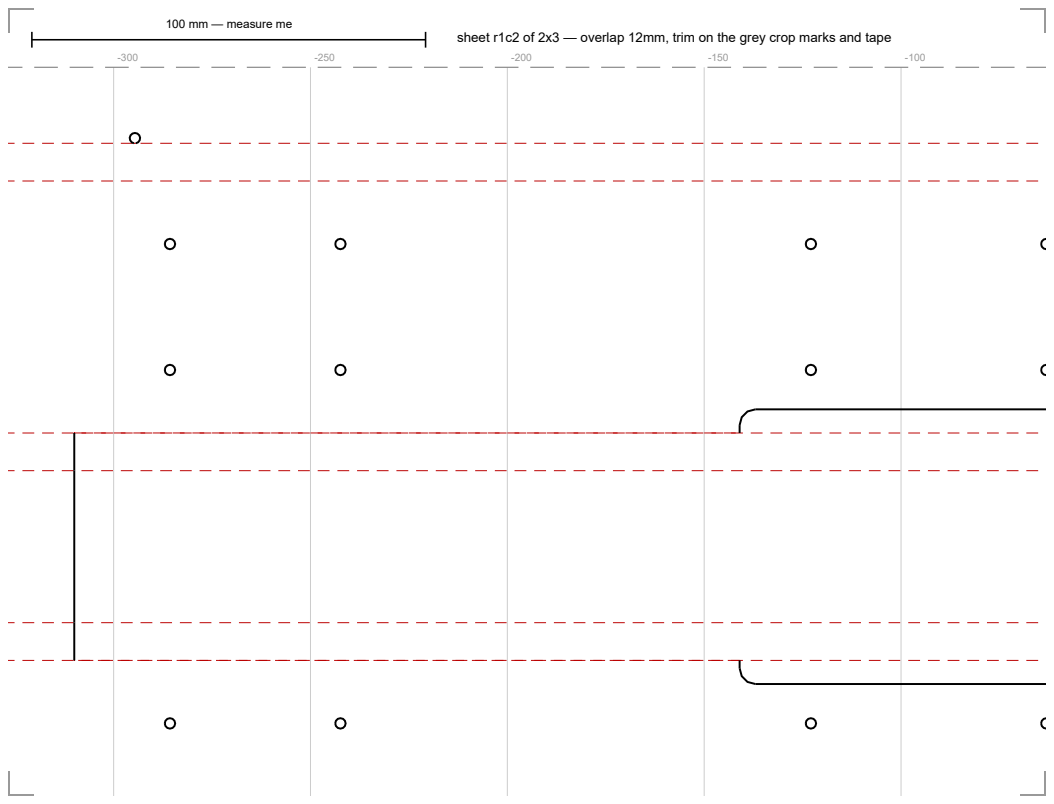
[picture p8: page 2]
rla; rim

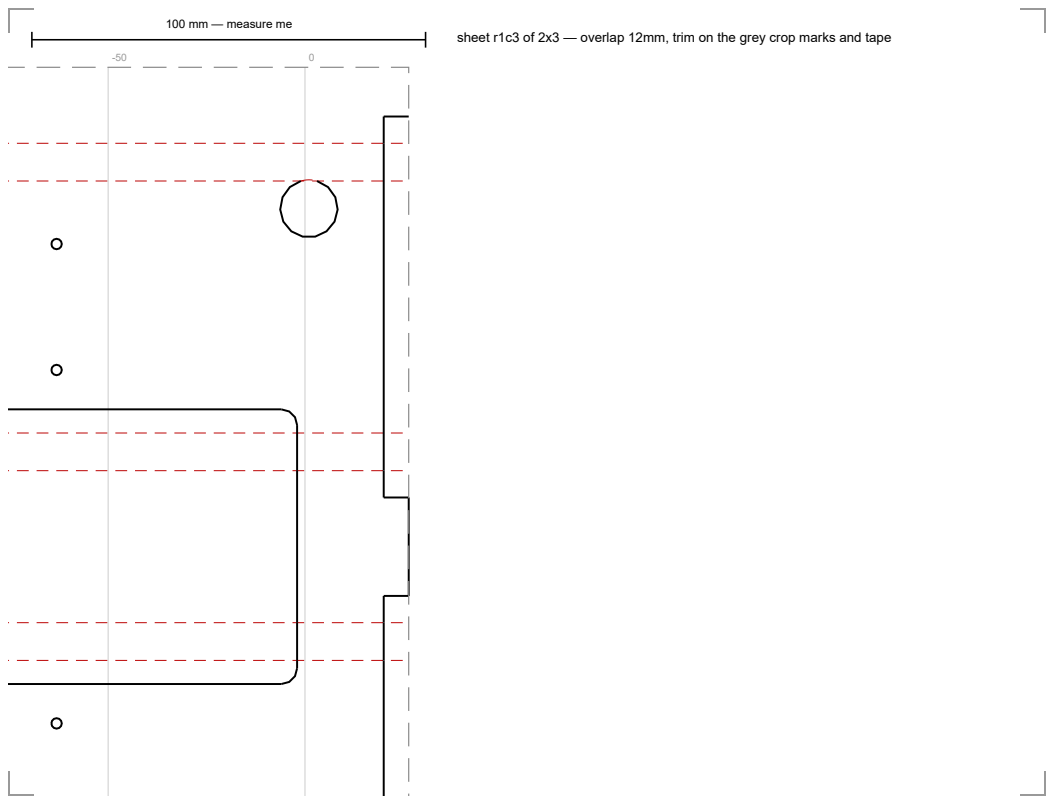
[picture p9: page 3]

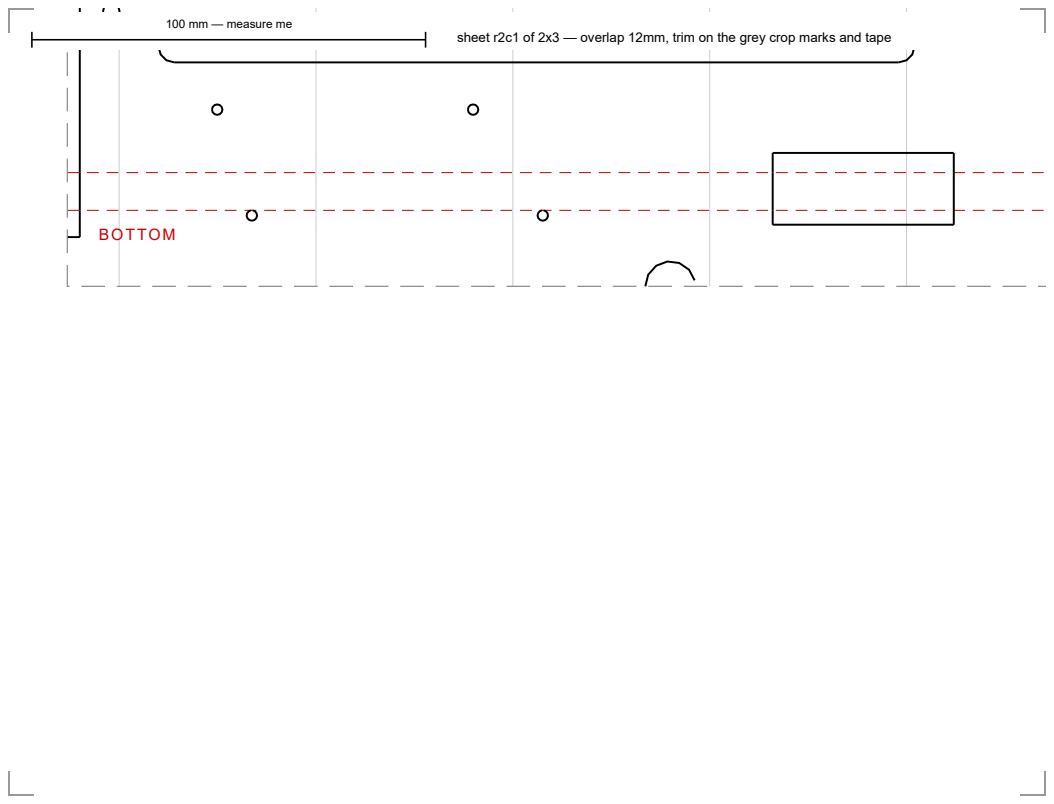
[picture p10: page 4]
LEFT SIDE; BOTTOM

100 mm — measure me

sheet r2c1 of 2x3 — overlap 12mm, trim on the grey crop marks and tape

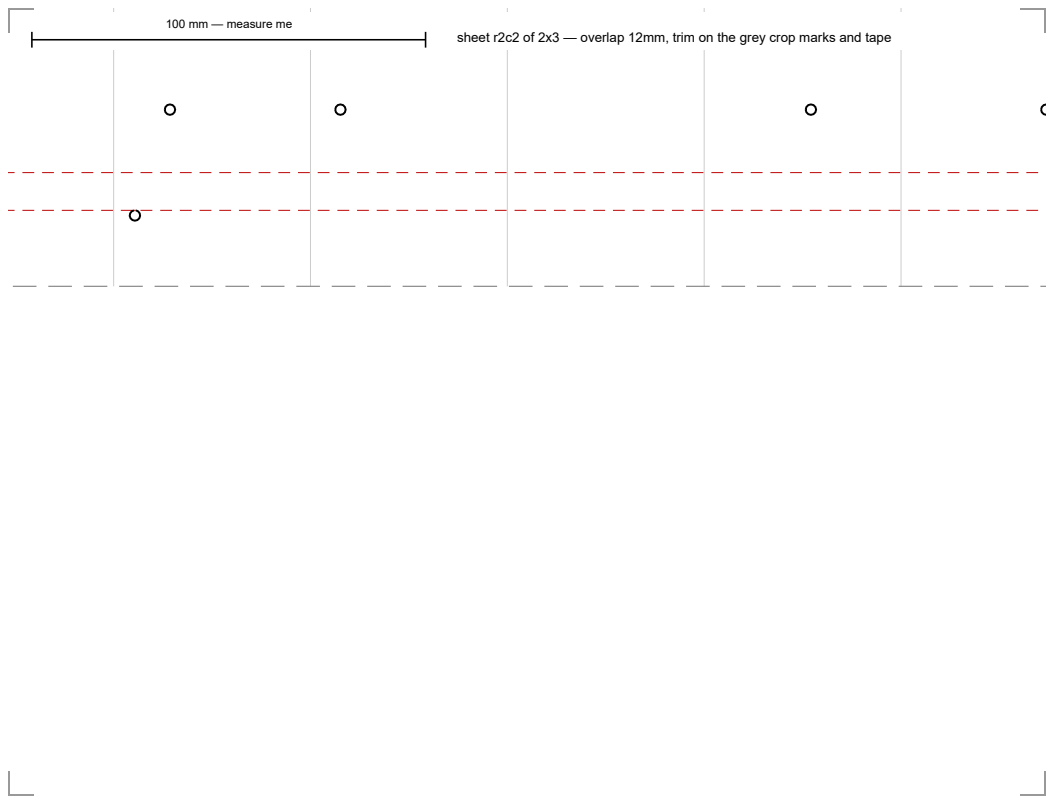
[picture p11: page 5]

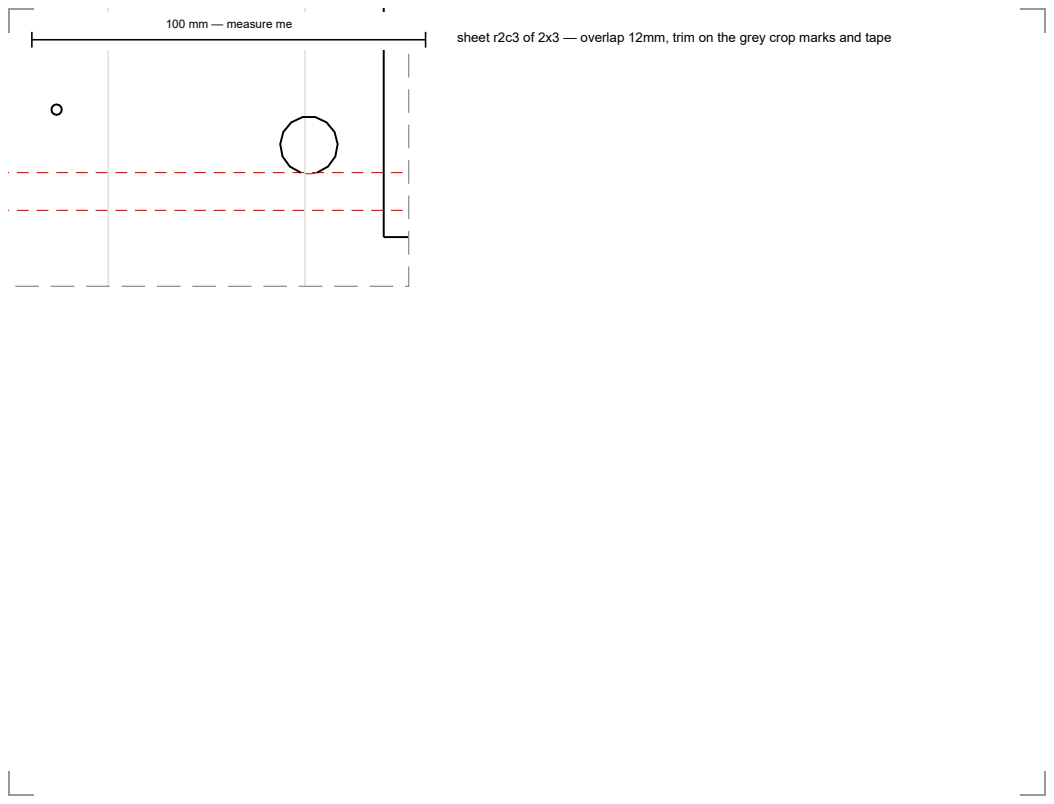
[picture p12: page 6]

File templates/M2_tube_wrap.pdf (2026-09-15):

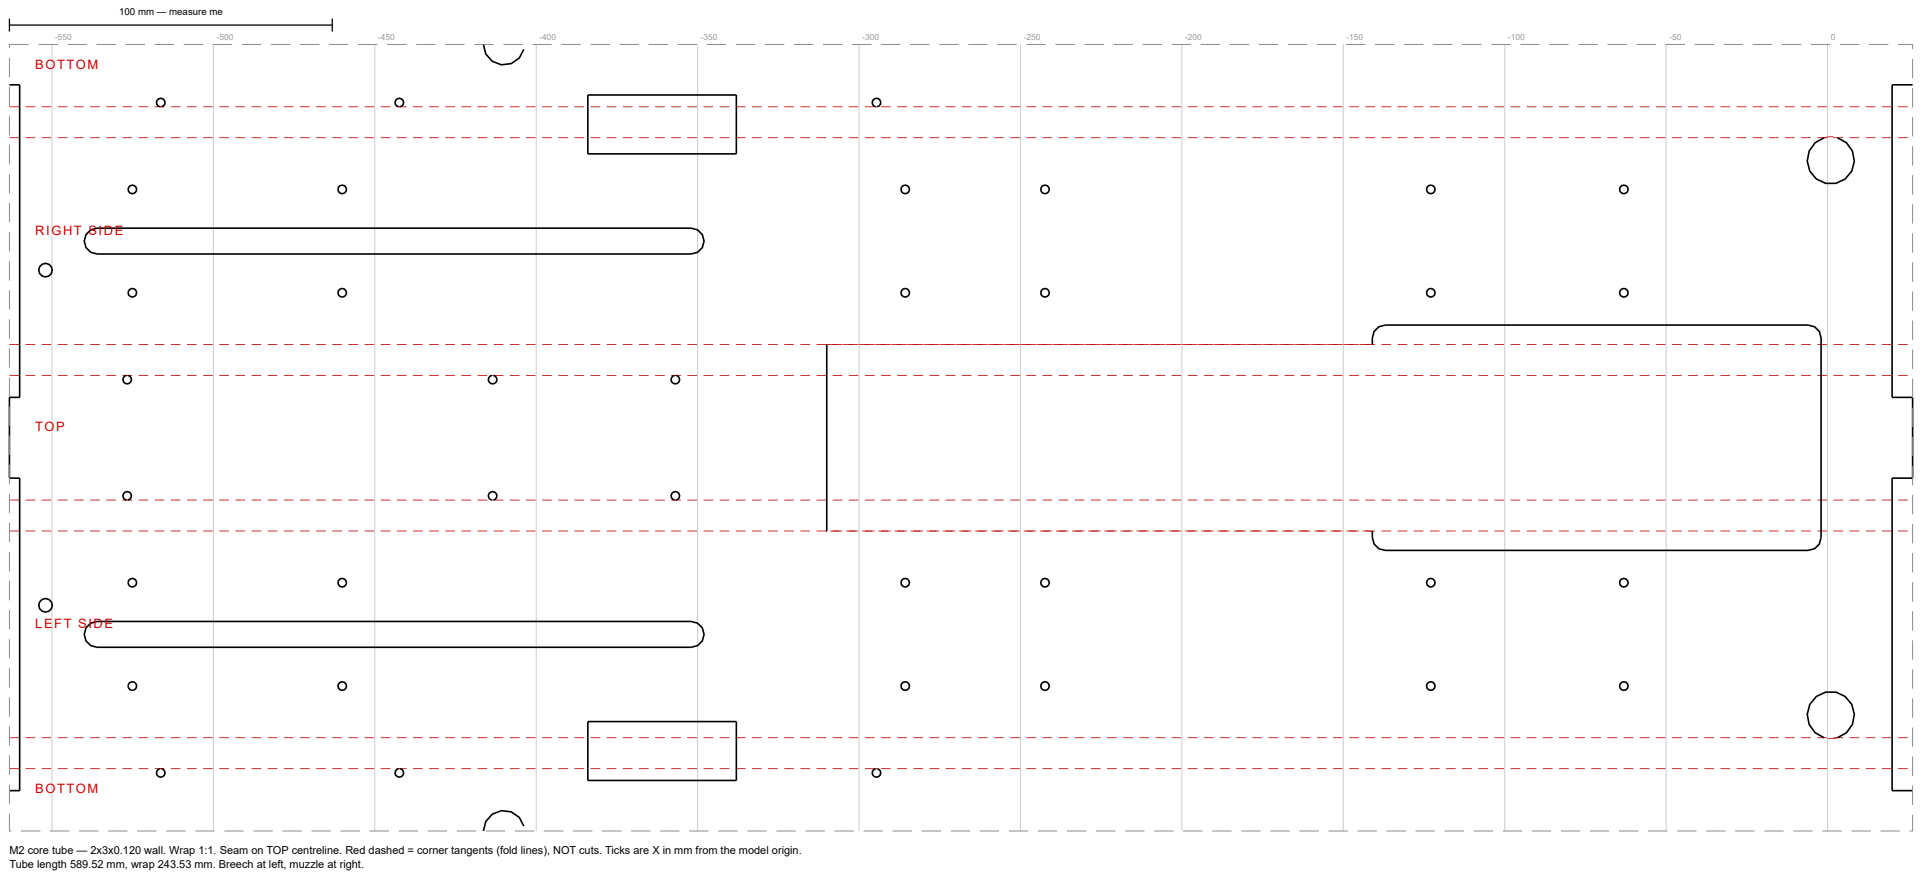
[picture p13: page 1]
BOTTOM; RIGHT SIDE; TOP; LEFT SIDE

100 mm — measure me

M2 core tube — 2x3x0.120 wall. Wrap 1:1. Seam on TOP centreline. Red dashed = corner tangents (fold lines), NOT cuts. Ticks are X in mm from the model origin.
Tube length 589.52 mm, wrap 243.53 mm. Breech at left, muzzle at right.

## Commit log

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2026-09-11 Design freeze: flush plates, straight top cut, backplate, STLs and source
    TUBE (589.52mm / 23.210in, 5.97 lb)
    - Top opening is now ONE straight cut at Z+24, full width. Z+24 is where the
    A500 corner radii begin so it lands flat on both side walls. Replaces the
    flanged Y+/-19 R5 opening, which fouled the hinge tabs and left messy
    geometry. Faces 89 -> 81.
    - Modelled with A500 corner radii, R0.240 outside / R0.120 inside. Without
    them OSH Cut's profile matcher reads the section as aluminium extrusion.
    - Locating tabs at both ends are exactly their plate thickness, so tab and
    plate faces finish flush. Nothing protrudes. Tabs pass through through-slots,
    keeping tube and plates laser-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
    [Bot1.stl, Bot2.stl, Cradle_F2_HopUp.stl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]
2026-09-11 Fix FrontBoss interference with the tube's front locating tabs
    The skin clearance envelope spanned X -561..+21, but the tube's front
    locating tabs reach X +26.35. The ~5mm of tab past the envelope was never
    relieved, so FrontBoss overlapped the tube by 0.5795 cm3.
    Extended the envelope to X -564..+27 so it covers the whole tube including
    the locating tabs at both ends. Regenerated all skins and re-exported.
    Full skin-vs-steel clash matrix now reads 0.0000 cm3 everywhere (FrontBoss
    0.0001 is tangency noise against the hatch spine). Volume conserved:
    sum of parts == union, 0.00 cm3 lost. All STLs watertight, normals correct.
    The core tube is unchanged -- 589.52 mm, 81 faces, 5.97 lb -- so t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
    [Bot1.stl, Bot2.stl, FrontBoss.stl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]
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2026-09-11 Size pin bores to imperial bar stock; credit the upstream model
    Three pin bores were modelled at round metric diameters while the stock list
    called out imperial bar. US bar is 6.35 / 12.70 / 14.29 mm, so the bar was
    larger than the hole in two of the three cases and would not have gone in:
    pintle 12.00 -> 13.00 takes 1/2" (+0.30)
    front mount 14.00 -> 14.60 takes 9/16" (+0.30)
    hinge 6.35 -> 6.65 takes 1/4" (+0.30)
    The hinge bore was nominally correct at exactly 1/4" but line-to-line, and
    that pin has to rotate. The Hatch and FrontBoss pin reliefs were opened to
    match. Skin-vs-steel clash still reads 0.0000 everywhere.
    ATTRIBUTION now names the source: M2 Br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
    [FrontBoss.stl, Hatch.stl, M2_core_tube_RFQ.stp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]
2026-09-11 Add working charging handle; bore the printed barrel for EMT
    Imported the upstream model pack's barrel, charging handle, trigger, grip
    and spring as reference geometry. All six parts share the corpus coordinate
    system, so they land in place with no transform.
    BARREL. Trimmed 1.95mm off the rear to clear the 1/4" barrel plate, bored
    d30.20 full length for the EMT, and counterbored d38.90 over the steel
    socket. 86.9mm of slip engagement on the socket, EMT passes clear, no
    overlap with any steel part. It is 984mm long and still needs sectioning
    for a 300mm bed.
    CHARGING HANDLE. The corpus slot I had projected onto the tube turned out
    to be a moulded detail line, not a track: the handle's shoe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
    [CH_Carrier.stl, M2_core_tube_RFQ.stp, M2_steel_core.stp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]
2026-09-11 EMT is the barrel; print only the perforated jacket
    Dropped the full-length printed barrel. 1" EMT conduit is the barrel itself,
    modelled as steel: X 13.65 (bottomed in the socket) to X 1010.5, 39-1/4",
    2.49 lb, clear of the socket, the plate and every skin with 0.64mm diametral
    clearance over the full 100mm of socket engagement.
    Kept the perforated jacket as a printed part -- it is the M2's identifying
    feature. X 26.75..287 (260.2mm), bored d38.90 over the steel socket and
    d30.20 for the EMT, with a centring ring at the muzzle end so it cannot flop
    on the conduit. Watertight, single shell, and it fits a 300mm bed stood on
    end with 40mm to spare. Clear of every steel part and every skin.
    T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
    [Barrel_Jacket.stl, M2_steel_core.stp, M2_steel_core_design.f3d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]
2026-09-11 Revert the CH aperture; run the handle in the existing 8mm slot
    I had enlarged the left wall to a 214 x 19mm track so the upstream
    charging.stl's 17.6mm shoe could pass through it. That was the wrong call:
    the donor shoe is discarded anyway -- the handle bolts to a carrier we
    make -- so the neck can be any size we want. It removed 4066mm2 of wall
    where 2032mm2 does the job, and forced an RFQ change for no benefit.
    Tube restored to 345.21 cm3 against the 345.15 it was before the aperture,
    and back to 5.97 lb. The slot is the original 192 x 8mm on both sides.
    Carrier redesigned around it: 7mm neck in the 8mm slot, 34mm long, so
    34 + 150 travel exactly fills the 184mm straight section. Rod mo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
    [CH_Carrier.stl, M2_core_tube_RFQ.stp, M2_steel_core.stp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]
2026-09-11 Bolt the handle to the carrier with 2x M6; add CH_Handle
    The handle had no connection at all -- there were two M4 holes in the pad
    but the donor part was never adapted, and it could not have reached them.
    Two measurements settle the geometry:
    Side_L1 is open only over X -540..-350
    the donor handle has material to bolt into only over X -320..-262
    The neck must stay in the panel opening; the bolts must go where the handle
    is solid. Those do not overlap, so the pad cantilevers 106mm forward from
    the neck at X -386..-352 out to X -280.
    I first tried moving the slot 28mm forward to sit under the handle, as
    asked. That does not work: it put the neck into solid panel (0.466 cm3) and
    the bol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
    [CH_Carrier.stl, CH_Handle.stl, M2_core_tube_RFQ.stp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]
2026-09-11 Drop the guide rod; sandwich the carrier on the wall
    Deleted CH_GuideRod_1-4 and both CH_RodTab weldments. The rod was a
    complicated part doing a job the slot already does, and it cost 0.128 lb of
    steel and two welded tabs. Steel is back to 9 weldments plus the tube.
    The mechanism is now three printed parts clamping the receiver wall:
    CH_Shoe inside the tube, Y -22..-14, 16mm tall behind an 8mm slot
    CH_Carrier 7mm neck through the slot, pad outside the panel
    CH_Handle full-length foot bolting to the pad
    Clamped stack is 7.65mm -- skin outer face to tube inner face -- across an
    8mm neck, so 0.35mm of running clearance. The shoe cannot pull out because
    it is twice the slot heig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
    [CH_Carrier.stl, CH_Handle.stl, CH_Shoe.stl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]
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2026-09-11 Trigger: switch above the tail, carrier registers off the tube
    Two real errors fixed.
    The switch was on the WRONG SIDE. Pressing the butterfly down at the rear
    swings the tail up, because the press point is behind and above the pivot --
    so the switch belongs above the tail. As built it sat below, where the lever
    would move away from it. It could never have fired.
    The switch was also 7.5mm out of reach of a lever that only travels 1.88mm,
    and the pocket meant to hold it had been cut outside the mount body
    entirely, so there was no pocket at all.
    Now specified to a real part rather than a guessed envelope: Omron SS-5GL13,
    body 19.8 x 10.2 x 6.4, holes d1.6 at 9.5mm pitch, OT min 1.0mm, OF 5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
    [M2_core_tube_RFQ.stp, M2_steel_core.stp, M2_steel_core_design.f3d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]
2026-09-12 Repair the grip mesh; add the grip and buffer tube as solids
    The donor grip mesh is not watertight, so it converted to a SURFACE body.
    A boolean against an open surface returns "no interference" regardless --
    there is no inside to find -- so the clash check I ran last time was
    meaningless. It was hiding 25.7 cm3 of overlap.
    tools/meshrepair.js fixes it. The defect turned out to be T-junctions rather
    than holes: 8 open edges whose four "loop" vertices are collinear, same X and
    Z with only Y varying, because one side of a seam used a single 66.6mm edge
    while the other used three shorter ones. Capping a zero-area loop with a
    centroid fan only makes degenerate triangles, which is exactly what m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
    [Buffer_Tube.stl, Grip_Spade.stl, M2_steel_core.stp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]
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2026-09-12 Close the FrontBoss/Barrel_Jacket gap; bond the joint
    FrontBoss ended at X 24.80 and the jacket started at X 26.75, leaving 1.95mm
    of the 1/4" barrel plate showing all the way round. My error: I trimmed the
    jacket to the plate's front face plus clearance instead of to FrontBoss.
    Extended rather than moved, so the muzzle stays at X 287. The jacket's
    section is constant over X 26.75..29.00 -- 2.235 cm3 at every slice -- so a
    1.95mm slice translated back gives an exact extrusion with no sketch needed.
    Pocketed Y +/-25.8, Z -46.5..30.5 to clear the plate. Jacket 876.21 ->
    880.68 cm3, now X 24.80..287.00, still one watertight shell, 262mm so it
    still stands on the bed.
    Verified clear of the pla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
    [Barrel_Jacket.stl, M2_steel_core.stp, M2_steel_core_design.f3d]
2026-09-12 Merge the grip and buffer tube into one printed part
    Grip_Assembly, 341.35 cm3, single watertight solid, 109 x 156 x 126mm so it
    still fits the bed. Rear printed part count drops from 3 to 2.
    Worth recording how: a plain union does NOT weld them. They meet at a
    coincident face with exactly 0.000 cm3 of overlap, and a boolean union of two
    bodies that merely touch returns 2 shells. Extending the buffer forward to
    start exactly at the joint face fails the same way, for the same reason.
    The fix is a bridge that STRADDLES the joint -- a 5.5mm slice of the buffer's
    own section translated forward 3mm, so it overlaps the buffer by 1.369 cm3
    and the grip by 1.654 cm3. Using the buffer's own section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
    [Buffer_Tube.stl, Grip_Assembly.stl, Grip_Spade.stl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]
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2026-09-12 Assembly audit: fix three interferences found by a global clash matrix
    First full every-body-against-every-body check of the assembly. 37 bodies,
    666 pairs. It found five clashes, three of them mine.
    Backplate bosses vs the grip, 1.614 cm3 each. The grip reaches forward to
    X -536.5 and carries material inside the tube's bore, which was empty when I
    relieved it -- the bosses now occupy that space. Grip relieved, -3.95 cm3.
    Tube vs both side skins, ~0.06 cm3 each. The d4.8 plug for the abandoned
    Z +6 pivot holes: I cut it out of the tube's interior but never trimmed it
    outside the wall, leaving two studs at Y 25.4..30 poking into the skins.
    Shaving the tube back to its Y +/-25.4 envelope rem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
    [FrontBoss.stl, Grip_Assembly.stl, M2_core_tube_RFQ.stp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]
2026-09-12 Resolve the skin fastening gap: 36 x M3 into the tube wall
    The last real design hole. Every receiver panel was "glue it somewhere".
    M3 thread-forming button-heads through the panel into d2.65 pilot holes in
    the tube wall. The wall is 0.120" so a thread-former cuts full depth on the
    way in -- no tap, no rivnut tool. Heads left proud so they read as the M2's
    rivet line rather than being hidden.
    Side_L1, Side_R1 6 each X -525.1/-460.1/-285.7, Z -24 and +8
    Side_L2, Side_R2 6 each X -242.4/-122.9/-63.1, Z -24 and +8
    Top1 6 X -526.7/-413.5/-356.9, Y +/-18
    Bot1 6 X -516.3/-442.4/-294.6, Y +/-18
    Positions were probed rather than assumed: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
    [Bot1.stl, M2_core_tube_RFQ.stp, M2_steel_core.stp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]
2026-09-12 Make the barrel removable without disturbing the jacket
    2 x M5 set screws tapped into the socket at X 55 and X 75, entering from
    underneath and bearing on the EMT. The socket is welded to the barrel plate
    so it is fixed and can be tapped; its wall is 3.96mm, enough for full M5
    thread.
    The tap hole stops at Z -15.05. Socket ID is r15.09 against an EMT OD of
    r14.77, so drilling any further cuts the EMT rather than leaving the screw to
    press on it. The screws close that 0.32mm radial gap -- dimple the EMT at
    both positions so they locate positively instead of relying on friction.
    X 95 was rejected because it lands on one of the jacket's cooling holes,
    where there is no material underneath to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
    [Barrel_Jacket.stl, M2_steel_core.stp, M2_steel_core_design.f3d]
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2026-09-13 Jacket: solid grip on the socket, flats at the receiver; add rebuild tracker
    Two corrections to the native jacket.
    The bore opened to d58.26 at X 46, so the jacket gripped the socket over only
    21mm and then floated with a 10mm radial gap for the next 67mm -- it would
    have wobbled on a 260mm part. The close d38.90 bore now runs to X 118, past
    the socket end at 113.65, giving 89mm of grip, and the perforations start at
    X 130 so the grip section stays solid. 550 -> 679 cm3.
    The rear flange was a plain disc. Measured off the donor it is flat at
    Y +/-29.8 with full r50.80 only in the 55-125 and 235-305 degree bands --
    that is where it meets the receiver, whose front is Y +/-30, so the flats sit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
    [Barrel_Jacket_native.stl, Barrel_Jacket_native.stp]
2026-09-13 Reauthor the hatch and top deck as native geometry
    Hatch 2,772 -> 122 faces, Top1 1,169 -> 49. Both within ~1% of the donor
    volume; Top1 is entirely planes and cylinders with no NURBS.
    Rebuilding the hatch exposed a real interference: the steel hinge tabs run
    straight through the solid nose of the cover, so it could not close. The
    earlier clash audit missed it because the boolean against the faceted donor
    body reported "clear" - a false negative. The native cover cuts the clearance
    as an r8.5 arc about the hinge pin, so the tab clears at every angle of the
    swing rather than only when shut. Verified at 0.00000 cm3 overlap.
    Method: scan for constant-section runs, slice exact profiles, straig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
    [Hatch_native.stl, Hatch_native.stp, Top1_native.stl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]
2026-09-13 Reauthor all eight convertible skins as native geometry
    39,131 faces of donor mesh replaced by 1,163 native ones - a 34x reduction
    across every part that was worth converting. Each is a single watertight
    shell, within 2.4% of the donor volume, and clear of all 12 steel bodies.
    Barrel_Jacket 17,422 -> 60 Side_L2 1,913 -> 93
    Hatch 2,772 -> 122 Side_R2 2,289 -> 84
    Top1 1,169 -> 49 Side_L1 6,631 -> 279
    FrontBoss 1,705 -> 304 Side_R1 5,230 -> 172
    The earlier note in the tracker claiming the side panels were freeform artwork
    was wrong. Measured properly they are linear rivet patterns, flat tiers at
    constant depth, and straight o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
    [FrontBoss_native.stl, FrontBoss_native.stp, Hatch_native.stl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]
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2026-09-13 Reauthor the grips and charging handle; domed rivets; bbox audit
    The last two parts are done. 66,886 faces of donor mesh are now 2,682 native
    ones - a 25x reduction - and every bounding box matches its donor to better
    than 0.25 mm in all three axes. Only the trigger's butterfly paddle is still
    faceted.
    I had marked CH_Handle and Grip_Assembly "not worth it - organic, knurled, the
    most sculptural parts on the gun". Both were wrong. The knob is a body of
    revolution about Y to 0.008 mm across 64 rays; the handgrips about Z to 0.006 mm
    across 48. They are turned, not knurled - each is now a single revolve of THREE
    faces. Ten thousand triangles made them look organic, which is the exact trap
    thi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
    [CH_Handle_native.stl, CH_Handle_native.stp, FrontBoss_native.stp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]
2026-09-14 One naming convention across Fusion, the STLs and the docs
    Every part now has a single name used identically in the Fusion browser, in
    stl/, and in the build notes:
    <class>-<NN>-<Name>[-L|-R] ST weld it, HW buy it, PR print it, RF reference
    Numbers group by subassembly: 0x structure, 1x receiver skins, 2x barrel,
    3x grips, 4x charging handle, 5x trigger, 6x engine. The browser is now nine
    components (10_Steel_Core, 20_Print_Receiver, ...) instead of a flat list of
    *_Native leftovers, and 21,952 faces of dead import duplicates that were sitting
    loose at the root are parked in 00_Ref_Import_Scrap.
    L AND R NOW MEAN THE PHYSICAL SIDES OF THE GUN. The charging handle on a real M2
    is on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
    [10_Steel_Core.stp, 11_Steel_Weldments.stp, 20_Print_Receiver.stp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]
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2026-09-14 Try lofting the grip frame between plan sections; reject it, keep the prisms
    The prisms leave a visible terrace at every band boundary on the yoke arms, so I
    sampled the plan at all 41 band boundaries and lofted between adjacent profiles
    wherever their topology matched - 31 lofted spans, 9 left stepped.
    It was worse on every measure and is not kept:
    volume -6.1% against -2.0% (a loft cuts the corner where a
    mid-band prism averages it)
    shells 2 against 1
    clashes 2 new - into PR-15-Top-Deck and PR-18-Bottom-Rear
    faces 415 NURBS where the prisms give planes
    Reverted to the banded prisms: 1,549 faces, one watertight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
    [40_Print_Grip.stp]
2026-09-14 Front boss: round pin bore, domed bosses, and a profile sampled off a boss
    The side-to-side through hole was a jagged square because it was never a hole -
    the hinge ears are built as rib slabs that stop at Z 59.4 and resume at Z 65.7,
    so the "bore" was just the rectangular gap between two slabs. Filled that gap
    across the bore's footprint in all four ears and drilled it: 369.0 mm2 of bore
    wall against 368.9 expected for a d6.65 hole through 17.66 mm of ear.
    Two more things were wrong in the same area, all from the same cause - anything
    running along Y gets sliced by each X run at a different chord and extruded flat,
    so round features come out as staircases:
    - three d6.6 domed bosses were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
    [20_Print_Receiver.stp, PR-17-Front-Sight-Boss.stl]
2026-09-14 Front boss: the mounting hole is blind, and finish filling the ear
    Two things were still wrong after the last pass.
    The front mounting hole is a BLIND countersunk pilot, one per side - d5.96 at the
    |Y| 30.0 face closing to d1.4 by |Y| 28.0 and bottoming at 27.8. I had drilled it
    straight through, which cut a slot clean across the part and out through the
    window behind it. The YZ section at X 14.72 now matches the donor exactly: solid
    to |Y| 32.3 with the window at |Y| 25.8, and no slot.
    The hinge ear fill only covered +/-3.6 mm about the bore, which left a 2.4 mm slot
    running out of it at X -5.40..-3.00 - the rib run is X -13.35..-3.0 and the donor
    ear is solid over all of it apart from th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
    [20_Print_Receiver.stp, PR-17-Front-Sight-Boss.stl]
2026-09-14 Front boss: census every hole instead of spot-checking one
    Three rounds of this part got declared fixed by checking whichever feature had
    just been complained about. Wrote tools/reauthor/holediff.js instead - walk both
    solids in parallel sections along an axis, match each hole to its nearest
    counterpart, report MISSING / EXTRA / wrong SIZE - and ran it on all three axes.
    It found in one pass what the eyeballing had missed:
    - two junk slots 0.70 and 0.65 mm tall, plus two of 0.00 mm. Pure mesh
    tessellation noise that the profile extractor had copied as real features,
    and precisely what was rendering as stripes. Now any hole under a millimetre
    in either direction is dropped.
    -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
    [20_Print_Receiver.stp, PR-17-Front-Sight-Boss.stl]
2026-09-14 Front boss: round the bottom scallop, and stop a run boundary faking a slab
    Two things were making this look wrong, and the previous commit made one of them
    worse.
    The scallop in the bottom edge is a CIRCLE - R 8.00 about (X 1.00, Z -33.40),
    least-squares fit to the donor outline at 0.00 mm, cut through the two walls at
    |Y| 25.8..30.0. The prismatic runs approximated it with a four-step staircase,
    which is the staircase visible along the bottom of the part. Trimming it back to
    the arc splits the part into seven shells, because those corners are load-bearing
    here; the fix is the other way round - fill the band beside it first, THEN cut the
    real cylinder. My boundary now sits at radius 8.00 a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
    [20_Print_Receiver.stp, PR-17-Front-Sight-Boss.stl]
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2026-09-15 Flatten the face the skins are printed on; they were sitting on six pads
    The panels had a 0.4mm clearance gap to the tube, and because a screw pulled across
    that gap would flex a 3mm shell, every fastener got a d8 boss on the panel's INNER
    face to bridge it. But the inner face is the face these parts print on - visible side
    up so the outside can be ironed. So each panel landed on the bed sitting on nothing
    but those bosses.
    tools/bedcheck.js, new here, measures it. Before:
    PR-13-Side-Front-L 2.46 cm2 on the bed, 216.69 cm2 floating 0.45mm above it
    PR-12-Side-Rear-R 2.46 cm2 on the bed, 334.91 cm2 floating 0.45mm
    PR-15-Top-Deck 2.46 cm2 on the bed, 105.91 cm2 floating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
    [PR-11-Side-Rear-L.stl, PR-12-Side-Rear-R.stl, PR-13-Side-Front-L.stl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]
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2026-09-16 Clear the four skin interferences instead of documenting them
    Last commit found these and wrote them down as known issues, on the reasoning that
    two looked like design questions - both lengthwise seams overlap by ~35 mm3 and might
    be intended lap joints. That was the wrong call. Two solids cannot share space
    whatever the intent; a lap still needs the clearance cut into one side of it. And one
    of the four was never a design question at all: PR-12 fouled the d4 trigger pivot pin
    by 20.1 mm3, which blocks assembly outright.
    tools/reauthor/resolve_clashes.py cuts all four at 0.20mm - deliberately more than the
    0.05 between a strip and a panel, because these are not faces meant to bed together
    b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
    [PR-12-Side-Rear-R.stl, PR-13-Side-Front-L.stl, PR-14-Side-Front-R.stl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]
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2026-09-16 Mouse-ear pads for the two 296mm panels, which are peeling off the bed
    Reported failure: PR-11/PR-12 lifting off a K1 Max. These are the 295.6mm parts. PLA
    contracts about 0.4% cooling, so each is trying to shrink ~1.2mm along its length,
    0.6mm at each end, and that force peels the end corners up. More glue stick does not
    address it - adhesion is not losing because the glue is weak, it is losing because
    peel at a corner loads a very small area.
    A brim is not available either, and that is a consequence of an earlier decision
    rather than bad luck: BUILD-NOTES puts the seam at X -265 because "max forward is
    X -260.6 before Side_1 exceeds the 300mm bed". At 295.6 on a 300 bed there is ~1.1mm
    of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
    [PR-11-Side-Rear-L-ears.stl, PR-12-Side-Rear-R-ears.stl]
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2026-09-16 PR-16 had the same standoff, and my diagonal-fit figure was an estimate
    The printer agent on the slicer machine came online and asked three questions.
    Answering two of them properly turned up two errors here.
    PR-16-Top-Cover has the SAME defect as the six skins: on the face it must print on
    it rested on 23.03 cm2 with 89.03 cm2 floating 0.15mm above. It survived four
    releases because it is not a tube-mating skin - it is the hinged cover - so it was
    never in scope, and the whole-matrix sweep I added was a CLASH check, not a bed
    check. Fixed the same way: 118.77 cm2 on the bed now, 0 clashing pairs still.
    It is the one part with no better option. x-min scores 64.4% against z-min but
    stands t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
    [PR-16-Top-Cover.stl]
2026-09-16 Pads add zero length: 297.6mm was unsliceable, and PR-16 never needed fixing
    The slicer agent came back with results and two findings that land on me.
    THE PADS MADE THE PART UNSLICEABLE. I set X_PROUD to 1.0mm - which read as
    conservative against 1.1mm of bed margin - and Creality Print refused to place the
    part at all: "Nothing to be sliced ... no object is fully inside the print volume".
    Not a slicing error, a placement rejection before Print::process.
    It bracketed the wall by scaling the real mesh: 297.6 rejected, 296.1 rejected,
    294.6 slices. PR-18 at 295.6 slices. A featureless box at 297.6 also slices. So the
    usable envelope for real geometry is tighter than 300 and tighter than for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
    [PR-11-Side-Rear-L-ears.stl, PR-12-Side-Rear-R-ears.stl]
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
